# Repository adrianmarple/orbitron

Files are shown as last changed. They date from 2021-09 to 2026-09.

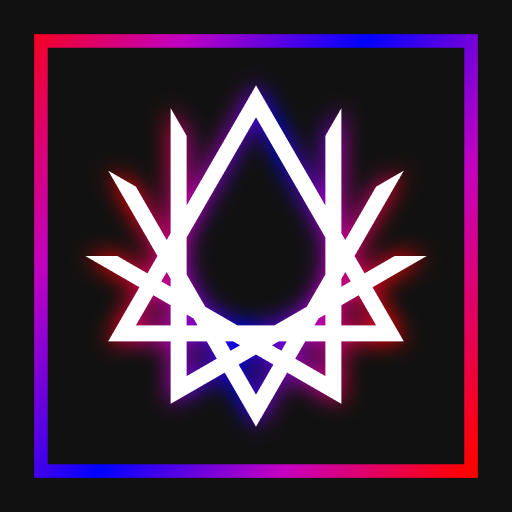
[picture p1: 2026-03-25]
controller/images/ravenstearborder.png

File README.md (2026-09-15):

# Basics

Lumatron is a LED sculpture system. You are free to play with this code, but as per the license you may not make money from it.

## TL;DR
```
       ┌──────────────┐  ┌──────────────┐  ┌──────────────┐
       │  Controller  │  │    Admin     │  │   Emulator   │
       │   (browser)  │  │   (browser)  │  │   (browser)  │
       └──────┬───────┘  └──────┬───────┘  └──────┬───────┘
              │ WSS :7777       │ HTTPS           │ WSS
              ▼                 ▼                 ▼
       ┌──────────────────────────────────────────────────┐
       │             Relay server (HTTPS + WSS)           │
       │           e.g. my.lumatron.art / localhost       │
       └──────┬─────────────────┬─────────────────────────┘
              │                 │                   ▲
              │ WSS             │ WSS (out)         │
              ▼                 ▼                   │
       ┌──────────────┐  ┌─────────────┐            │ stls
       │ Raspberry Pi │  │   Arduino   │◄─────────┐ │
       │ Node + Py    │◄─│  esp32.ino  │──────────┤ │
       └──────┬───────┘  └────┬────────┘   pixels │ │
              │ drives        │ drives       info │ │
              ▼               ▼                   │ │
       ╔═══════════════════════╗         ┌────────┴─┴────┐
       ║   Physical piece      ║◄────────┤   Creation    │
       ║   (LED sculpture)     ║ designs │ console (dev) │
       ╚═══════════════════════╝         └───────────────┘
```

- Orbs always connect *outbound* to the relay, so they work behind NATs without port forwarding.
- The relay routes controller / admin / emulator messages to the right orb over its open WebSocket, and serves the websites for the controller, admin, and emulator.
- The Creation console is a dev-time tool (port 8000): it designs the physical piece (3D-printable parts) and writes geometry (pixel info and stls) into the repo.
- Each physical piece is driven by exactly one orb (Pi *or* Arduino).
- In dev (`DEV_MODE: true`), a single machine plays all roles: relay, local Pi-style orb, and emulator standing in for a real piece.

## Connecting an existing piece to the internet

Here's how to connect a piece that does not already have an internet connection (if no piece is already connected to the same wifi you're on these instructions can also be viewed by visiting `https://my.lumatron.art`)
- Plug in the Lumatron box into the power source and the box into the piece (do not plug the piece directly into the usb-c wall plug)
- Wait for the box to boot up and the access point pattern (waves eminating from the bottom point) to show (takes a couple minutes for the raspberry pi based boxes)
- Join the wifi named Lumatron-*name*
- (If the captive portal doesn't automatically appear) visit 10.42.0.1 in your browser.
- Enter the wifi name (SSID) and password in the captive portal
- Visit or refresh `https://my.lumatron.art` once the first pixel turns off

## Controlling a piece

- Visit `https://my.lumatron.art`
- (optional) Turn the site into a progressive web app by following the instructions at the bottom of the page

# Using the Emulator

- Clone (optionally fork first) this repo (`git clone https://github.com/adrianmarple/orbitron`) on your local machine (Windows not supported)
- cd to the root of the repo (folder should be named `orbitron`)
- Install node if you haven't already
- Run `scripts/admin_install.sh` (in the `scripts` folder of the newly cloned repo)
- Start the emulator by running `sudo ./startscript.sh`
- Visit `http://localhost:1337` for the controller
- Visit `http://localhost:1337/test/view` for the emulator (which also contains a controller)

## The admin console

- Make sure you've run `./admin_install.sh`
- Ensure the local server (`sudo ./startscript.sh`) is running
- Visit url `http://localhost:1337/admin`
- Follow instructions for entering a master key
- More details in [the admin folder README](admin)

# Designing a new pattern

See [the idlepatterns folder README](idlepatterns)

# Making a new Game

See [the games folder README](games)

# Setting up your own server

- Fork this repo
- Create an ubuntu server, for instance the lumatron.art is currently hosted through [Digital Ocean](https://www.digitalocean.com/)
- Add a domain (or subdomain of an existing domain you control) to the server (this is required to serve over https)
- Wait and make sure the DNS records are in place (i.e. by checking [https://www.whatsmydns.net/](https://www.whatsmydns.net/))
- Open a console into root of your new server
- Clone your forked repo, i.e. `git clone https://github.com/YOUR_GITHUB_NAME/orbitron`
- Run `cd orbitron` then `scripts/server_install.sh` and enter your domain (and eventually email and other certbot prompts)
- Test by visiting `https://your_domain.com` (you should see "No pieces found on the same wifi")

## Connect a piece to your own server

- Arduino
  - Clear entire arduino flash `esptool.py --chip esp32c3 --port /dev/ttyUSB0 erase_flash`
  - Edit arduino/esp32/esp32.ino: find and replace "my.lumatron.art" with your server
  - Install adruino cli if you haven't already: `scripts/arduino_install.sh`
    - Note two github hooks are installed with this script. One runs `scripts/arduino_build.sh` on git push and uploads the compiled firmware to the server
    - The server url is currently hardcoded, so you should edit "arduino_build.sh" to use your own server, if you want to push to your own repo.
  - Upload to the arduino using `scripts/arduino_upload.sh`
- Raspberry pi
  - Request an unlocked SD along with a piece, email adrian@marplebot.com an request it be unlocked remotely, or follow the **Micro SD card setup** instructions below
  - Get local IP address (once the admin console is set up, you'll be able to get the ip address directly from there)
    - MacOS: `sudo nmap -sn $(ipconfig getifaddr en0)/24`
    - Linux: `sudo nmap -sn $(hostname -I | cut -d' ' -f1)/24`
  - `ssh pi@<IP address>` (password `lumatron`) into the piece
  - Change the password by running `passwd`
  - Edit `orbitron/config.js` to add the line `RELAY_HOST: "your-domain-or-ip",` (also remove `ORB_KEY` if it's there)
  - Run `pm2 restart all`
- Test by visiting `https://your_domain.com` again (you should now see the piece)

## The admin console

- Ensure your server is properly set up
- Visit url `https://your-domain.com/admin`
- Enter the masterkey (from `masterkey.txt` from your server's console) as prompted
- I recommend hitting the "Set ORB_KEY" button followed by the "Save config.js" button for all connected orbs (including the server itself - default named "demo")
  - Note: if this button is not visible hit the "config" button first
- Again see [the admin folder README](admin) for more details

## Continuous integration

You can set up pieces so that pushing to github automatically triggers pieces to restart and pull changes:
- Direct a github action to point to your server
- Add `CONTINUOUS_INTEGRATION: true,` to the config of a piece you want to restart on receiving updates

# REST API

Most things the controller can do can also be done over plain HTTP (useful for scripting: Home Assistant, Shortcuts, cron, or any other forms of automation). This includes preferences, saved presets, the timer schedule, and dimming, but omits game inputs. It is served by the server (i.e. `my.lumatron.art`) under `/api/v1`.

`GET /api/v1/orbs` lists the pieces available to you. Every other path is relative to `/api/v1/orbs/<piece>`, where `<piece>` is a piece's name or its alias (e.g. `https://my.lumatron.art/api/v1/orbs/kitchen/prefs`).

| Method | Path | Body | Description |
|---|---|---|---|
| `GET` | `/prefs` | — | All current settings (pattern, colors, brightness) |
| `PATCH` | `/prefs` | `{"<key>": value, ...}` | Change one or more settings, leaving the rest alone |
| `DELETE` | `/prefs` | — | Reset all settings back to defaults |
| `POST` | `/dim` | — | Step brightness, the same as the hardware button |
| `GET` | `/presets` | — | Saved preset names, which one is current, and cycle membership |
| `PUT` | `/presets/<name>` | — | Save the current settings as `<name>` |
| `POST` | `/presets/<name>/load` | — | Switch to `<name>` |
| `DELETE` | `/presets/<name>` | — | Delete `<name>` |
| `POST` | `/presets/<name>/copy` | `{"copyName": "..."}` | Copy `<name>` to a new preset |
| `POST` | `/presets/<name>/rename` | `{"newName": "..."}` | Rename `<name>` |
| `POST` | `/presets/<name>/reorder` | `{"targetName": "..."}` | Move `<name>` in front of `targetName` |
| `POST` | `/presets/cycle` | — | Advance to the next preset in the cycle |
| `GET` | `/schedule` | — | Timer settings, plus the daily and weekly schedules |
| `PUT` | `/schedule` | `{"useTimer": true, "schedule": [...]}` | Update timer settings |
| `GET` | `/state` | — | All of the above at once |

Preset names may contain spaces, so URL-encode them (`/presets/Evening%20Glow/load`).

A few things worth knowing:
- There's no authentication by default, which is the same as the controller — anyone who knows a piece's name can already control it. To lock it down, add `REST_API_KEY: "some-secret",` to your server's `config.js` and send `Authorization: Bearer some-secret` with every request.
- `GET /api/v1/orbs` only lists pieces on the same wifi as whoever is asking, so the whole fleet isn't enumerable.
- The API connects to a piece the same way a controller does, but without claiming one of the six player slots, so it won't interfere with games or with anyone using the controller. Changes made either way show up in the other immediately.

See [API.md](API.md) for the full endpoint reference.

# Contributions Welcome

Here's a list of things I would welcome receiving PRs for.

- New idle patterns — See [idlepatterns/README.md](idlepatterns/README.md) for details
- New games — See [games/README.md](games/README.md) for details
- Clarifications or other improvements to any READMEs
- UX improvements or other quality of life features for the controller
- General optimizations or improvements

# Arduino setup
Requires a Xiao esp32c3, esp32c6, or esp32s3
- Run `scripts/arduino_install.sh`
- Plug into your computer
- Run `scripts/arduino_upload.sh` to compile and upload to your arduino
- For the first time after installing, check for an access point and add a wifi connection

# Raspberry Pi setup

- Download [an unlocked SD card image](https://www.dropbox.com/scl/fi/ce7uv4ptdwy640emwvc8e/lumatron.zip) from dropbox
- Burn to SD card using `dd` or [Balena Etcher](https://etcher.balena.io/)
- Using `dd`
  - Update `/dev/disk4` or `/dev/sda` below with the correct drive as determined from `diskutil list` or `lsblk` on Linux
  - `diskutil unmountDisk /dev/disk4` or `sudo umount /dev/sda1 && sudo umount /dev/sda2` on Linux
  - go to Download directory or wherever the SD image download is
  - `sudo dd if=lumatron.img of=/dev/disk4 status=progress`
  - On MacOS use `gdd` instead
    - Install with `brew install coreutils`
    - `sudo gdd if=lumatron.img of=/dev/disk4 status=progress`
- Insert SD card into raspberry pi and power on
- Connect via `ssh pi@<<IP_ADDRESS>>` password `lumatron`
- Change to your own password

## (alternative) Fresh Setup

### Image an SD card

- Download Raspberry Pi Imager: https://www.raspberrypi.org/software/
- Select the latest 64-bit Raspberry PI OS
- Click the gear icon to change the settings of the install
- Set hostname to `orbitron`
- Enable SSH with password authentication
- enter pi as the username and enter a password
- Configure wireless LAN to connect to your local wifi
- Set timezone and select us Keyboard layout
- Save and click `WRITE` to burn the image
- Plug SD Card into PI

### Getting connected

- Connect PI to monitor/TV via HDMI cable
- Connect USB keyboard to PI as well
- Power on the PI
- Wait for some time, it may need to reboot 2 or more times
- You should see `orbitron login:` when it is ready
- Login with the username and password you set

### Install git

- `sudo apt install git`

### Clone Repo and run installer

- `git clone https://github.com/adrianmarple/orbitron`
- `~/orbitron/scripts/pi_install.sh`

# Additional useful things of note

## Ripping a new SD card version
- Update `/dev/disk4` below with the correct drive as determined from `diskutil list` or `lsblk`
- `sudo dd if=/dev/disk4 of=lumatron.img bs=8M count=820 status=progress`
- On MacOS use `gdd` instead
  - Install with `brew install coreutils`
  - `sudo gdd if=/dev/disk4 of=lumatron.img bs=8M count=820 status=progress`

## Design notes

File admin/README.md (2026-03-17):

# Basic setup

- Run `./admin_install.sh` (in the `scripts` folder)
- Local version:
  - Run the local server `sudo ./startscript.sh` in the repo root
  - Visit url `http://localhost:1337/admin`
- Server version (assuming you've setup your own server):
  - Visit url `https://your-domain-or-ip/admin`

# Admin console

Note, each Lumatron piece in code is called an "orb" (for legacy reasons related the former name, Super Orbitron).

## "Orb" list (right side)

The right side features a list of all orbs connected to the relay (or local relay if using `?local`). This list gets checked every 10 seconds.

## Functions (left side)

### Editing "orb" local files

There are 3 files that can be edited directly by clicking on the corresponding button and either typing ctrl-s or hitting the corresponding "Save [X]" button (which will restart the corresponding orb).
- config: this is the most important one. It lets you change the fundamentals of the orb. Check `config.js.template` in the repo root for examples.
  - When in this view there are "Generate ORB_ID" and "Set ORB_KEY" buttons visible.
    These edit the scratch `config.js` in the center, but you still need to save for them to take any effect.
- prefs: the `prefs.json` that controls the idle patterns, same as is manipulated by a controller.
- timing: the `timingprefs.json` that saves all other pref values, including dim state.

### Other commands

- Issue commands: a cheap ssh-like capability I added to be able to handle edge cases
  - Unlock Orb: resets the pi's password to "lumatron"
- All Backups: allows you to restore any orb from backup (saved by each orb at midnight), or force a manual save now with a custom name.
- Power Calibration: used to figure out the max power of an orb; used when in sight of the orb being calibrated
- Restart: self-explanatory
- Controller: opens the controller for this orb in a new tab (even if not connected to the same wifi)

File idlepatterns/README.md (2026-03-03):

# Idle Patterns

Idle patterns are the LED animations displayed when no game is active. Each pattern is a Python file that subclasses `Idle` (from `idlepatterns/__init__.py`), which itself subclasses `Game`.

## How It Works

`__init__.py` defines the `Idle` base class and the `set_idle()` function. When the active pattern changes (via controller prefs), `set_idle()` dynamically imports the new pattern module and calls `engine.start()` on it.

Each pattern overrides `render()` (or uses the base class rendering pipeline) to write values into `engine.raw_pixels` each frame. The base `Idle.render()` provides:
- **Frame pacing** — waits until the next frame is due
- **Fade** — applies `prefs.fade()` decay to `render_values`
- **Blending** — smooth interpolation between frames via `blend_pixels()`
- **Color** — applies color mode (fixed, rainbow, gradient, tricolor) via `apply_color()`
- **Brightness** — scales output by brightness pref (quadratic) and beat factor

## Adding a New Pattern

- Create `idlepatterns/mypattern.py`
- Subclass `Idle` and set `name = "mypattern"`
- Override `update()` for per-frame logic and/or `render()` for full custom rendering
- Add the pattern to `patternOptions()` in either the `options` list or the `includableOptions` list
  - If in `includableOptions` you'll need to add `INCLUDE: {mypattern: true},` to an orb's config for it to appear in that orb's controller
- If you want any additional parameters visible in the controller
  - Add them to the `default_prefs` dict in `prefs.py`
  - Access them via `prefs.get_pref('mypref')` in `mypattern.py`
  - Add new UI elements in `controller.html` to the `<!-- PATTERN MENU -->` section, imitating existing examples. Make sure to condition on that pattern being selected

## Existing Patterns

| Pattern | Description |
|---|---|
| `default` | Fluid fire that spreads via neighbor graph, squared brightness. Defined in `__init__.py`. |
| `fireflies` | Like default without branching and with directional propagation bias (`patternBias`). |
| `static` | Directional gradient — dot product of pixel coords with a direction vector. Optionally rotates over time. |
| `sin` | Traveling or radial sine wave along a configurable direction. `sinMin` sets brightness floor. |
| `linesine` | Sine wave along a 1D line/ring topology. Only valid when no pixel has more than 2 neighbors. |
| `pulses` | Expanding spherical ring pulses spawned from random points. Width controlled by `rippleWidth`. |
| `lightfield` | Each pixel oscillates independently at a random frequency and phase. |
| `lightning` | BFS spanning tree from a random sink; traces paths from random sources with exponential distance falloff. |
| `hourglass` | Fills pixels top-to-bottom over a configurable daily time window (`hourglassStart`/`hourglassEnd`). |
| `weather` | Sine wave modulated by live weather data (wind direction, temperature, UV, rain) via OpenWeatherMap. Requires `LAT`, `LON`, and `WEATHER_API_KEY` in `config.js`. |

## Key Prefs

Most patterns read from `prefs.py` via `get_pref()`. Common ones:

| Pref | Used by |
|---|---|
| `idleDensity` | default, fireflies, lightning, pulses, sin |
| `idleFrameRate` | all (speed, only related to frameRate for default and fireflies) |
| `idleBlend` | all (blend smoothing) |
| `idleColor` | all (color mode) |
| `brightness` | all |
| `patternBias` | fireflies |
| `staticDirection`, `staticRotation`, `staticRotationTime` | static |
| `sinDirection`, `sinMin`, `sinRadial` | sin, weather |
| `rippleWidth` | pulses |
| `hourglassStart`, `hourglassEnd` | hourglass |

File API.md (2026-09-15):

# Lumatron REST API

A JSON HTTP API for preferences, saved presets, and the timer schedule.
It is served by the **relay** under `/api/v1`.

Internally it connects to each orb as a virtual controller client, speaking the same WebSocket
message set `controller/controller.js` uses. Nothing is special-cased per device, so it works
identically for Raspberry Pi orbs and Arduino (ESP32) orbs.

```bash
curl -X PATCH https://my.lumatron.art/api/v1/orbs/myorb/prefs \
  -H 'Content-Type: application/json' \
  -d '{"brightness":40,"idlePattern":"fireflies"}'
```

## Authentication

None by default — the same exposure the WebSocket controller already has, where knowing an orb ID
is enough to control it.

To require a token, set `REST_API_KEY` in `config.js` on the relay; every request must then send
`Authorization: Bearer <that value>` or get `401`.

Orbs with `REQUIRES_LOGIN` cannot be driven through this API at all: they expect a 4-digit code
displayed on the orb itself, which a headless client can't read. Those return `403`.

## Orb IDs

The `:orb` path segment accepts either the orb ID or its alias (added to the relay's config.js).

---

## Endpoints

### Orbs

| Method | Path | Description |
|---|---|---|
| `GET` | `/api/v1/orbs` | Orbs on the caller's own network |

Scoped by source IP, so other orbs aren't exposed. Orbs configured with `NO_LOCAL_REGISTRATION` are omitted.

```json
[ { "id": "myorb", "alias": "kitchen", "isArduino": false, "connected": true } ]
```

### State

| Method | Path | Description |
|---|---|---|
| `GET` | `/api/v1/orbs/:orb/state` | The orb's lighting state in one call |

`prefs`, `prefNames`, `currentPrefName`, and `currentText`. `gameInfo` is omitted, since this API
doesn't cover games.

### Preferences

| Method | Path | Body | Description |
|---|---|---|---|
| `GET` | `/api/v1/orbs/:orb/prefs` | — | All current preferences |
| `PATCH` | `/api/v1/orbs/:orb/prefs` | `{"<key>": value, ...}` | Set one or more preferences |
| `DELETE` | `/api/v1/orbs/:orb/prefs` | — | Reset to defaults (`clearPrefs`) |

`PATCH` is a partial update — omitted keys are untouched. Unknown keys are rejected with `400`
rather than silently dropped, so a typo is visible:

```json
{ "error": "Unknown preference(s): brightnes" }
```

The authoritative key list is whatever `GET /prefs` returns for that orb, since it varies with
firmware version. The main ones:

| Key | Type | Default | Pi only | Description |
|---|---|---|---|---|
| `idlePattern` | enum | `"default"` | | Which animation runs: `default`, `static`, `fireflies`, `lightning`, `pulses`, `sin`, `lightfield`, `hourglass`, `linesine`, `weather`. `hourglass` and `weather` are Pi only. An orb's config can override the default with `IDLE`. |
| `idleFrameRate` | number | `15` | | Animation speed, for every pattern — an actual frame rate only for `default` and `fireflies`. Controller range 5–30. |
| `idleBlend` | number | `60` | | How much of the previous frame each frame blends in (motion smear). Unused by `weather`, `static`, `sin`, `lightfield`. |
| `idleDensity` | number | `70` | | How much is lit at once — head/source count for `default`, `fireflies`, `lightning`, `pulses`, `sin`. Minimum 10. |
| `staticRotation` | bool | `false` | | `static`: sweep the direction over time instead of holding `staticDirection`. |
| `staticRotationTime` | number | `8` | | `static`: seconds per full rotation, when `staticRotation` is on. |
| `staticDirection` | vector | `"1,1,0"` | | `static` (and `hourglass`): the axis the gradient runs along. |
| `patternBias` | vector | `"0,1,0"` | | `fireflies`: the direction the fireflies tend to travel. |
| `useBias` | bool | `true` | ✓ | The controller's "Use bias" toggle beside `patternBias`. Stored only — the render pipeline always applies the bias vector. |
| `rippleWidth` | number | `9` | | `pulses`: width of each expanding ring, 1–50. |
| `sinDirection` | vector | `"1,0,0"` | | `sin`: the direction the wave travels. Ignored when `sinRadial` is on. |
| `sinMin` | number | `25` | | `sin`: the trough value; the wave always peaks at 255. Negative values (down to -255) render as black but still shape everything above the trough. |
| `sinRadial` | bool | `false` | ✓ | `sin`: waves start at the center and move outward instead of travelling along `sinDirection`. |
| `sinRadialReverse` | bool | `false` | ✓ | `sin`: with `sinRadial` on, move inward instead. |
| `sinWaveCycles` | number | `4` | | `linesine`: how many wave cycles fit around the line/ring, 1–10. |
| `disableBeatMode` | bool | `false` | ✓ | `default`: opt out of beat-reactive brightness, on orbs wired for it (`BEAT_PIN`). |
| `hourglassStart` | `"HH:MM"` | `"00:00"` | ✓ | `hourglass`: when the daily fill begins. |
| `hourglassEnd` | `"HH:MM"` | `"23:59"` | ✓ | `hourglass`: when it finishes. |
| `idleColor` | enum | `"gradient"` | | Color mode: `rainbow`, `fixed`, `gradient`, `tricolor`. |
| `brightness` | number | `100` | | Master brightness, applied quadratically. |
| `color1` | color | `"#25ff59"` | | `fixed`: the one color everything is drawn in. `gradient`: the color the brighter pixels take. `tricolor`: the first band. |
| `color2` | color | `"#00607c"` | | `gradient`: the color the dimmer pixels take. `tricolor`: the middle band. Unused by `fixed`. |
| `color3` | color | `"#ff00aa"` | | `tricolor`: the last band. Unused by every other mode. |
| `gradientThreshold` | number | `66` | | `gradient`: where the two colors meet — lower is more `color1`, higher is more `color2`. `tricolor`: where `color3` gives way to `color2`. Minimum 1. |
| `gradientThreshold2` | number | `100` | | `tricolor`: where `color2` gives way to `color1`. Unused by every other mode. Minimum 1. |
| `rainbowDuration` | number | `10` | | `rainbow`: seconds for one full cycle through the rainbow. |
| `rainbowFade` | number | `0` | | `rainbow`: how much of the rainbow is on the orb at once. `0` is a single solid color cycling over time. |

A ✓ in "Pi only" means the Arduino (ESP32) firmware doesn't carry that pref at all, so it never appears in that orb's `GET /prefs` and `PATCH`ing it returns `400 Unknown preference(s)`.

Colors are `#rrggbb` strings; directions are `"x,y,z"` strings.

The color slots and blend thresholds used to be one set per mode. Those names are still
accepted on `PATCH` and mapped onto the merged keys above, so existing scripts keep
working — but they are never reported back by `GET /prefs`, and a preset re-saved after
being loaded is rewritten with the new names:

| sent | applied as |
|---|---|
| `fixedColor` | `color1` |
| `gradientStartColor`, `gradientEndColor` | `color1`, `color2` |
| `tricolor1`, `tricolor2`, `tricolor3` | `color1`, `color2`, `color3` |
| `tricolorThreshold1`, `tricolorThreshold2` | `gradientThreshold`, `gradientThreshold2` |

`tricolor` needs an explicit `INCLUDE` in an orb's config to appear in the controller's
mode dropdown, but the API can select it either way.

### Brightness / dimmer

| Method | Path | Description |
|---|---|---|
| `POST` | `/api/v1/orbs/:orb/dim` | Step through `MANUAL_FADE_STEPS` (default on/off) |

The same action as the orb's hardware button and the controller's power button.

### Presets

| Method | Path | Body | Description |
|---|---|---|---|
| `GET` | `/api/v1/orbs/:orb/presets` | — | `{names, current, includedInCycles}` |
| `PUT` | `/api/v1/orbs/:orb/presets/:name` | — | Save current prefs as `:name` |
| `DELETE` | `/api/v1/orbs/:orb/presets/:name` | — | Delete `:name` |
| `POST` | `/api/v1/orbs/:orb/presets/:name/load` | — | Load `:name` |
| `POST` | `/api/v1/orbs/:orb/presets/:name/copy` | `{"copyName": "..."}` | Copy to a new name |
| `POST` | `/api/v1/orbs/:orb/presets/:name/rename` | `{"newName": "..."}` | Rename |
| `POST` | `/api/v1/orbs/:orb/presets/:name/reorder` | `{"targetName": "..."}` | Move before `targetName` |
| `POST` | `/api/v1/orbs/:orb/presets/cycle` | — | Advance to the next preset in the cycle |

Preset names may contain spaces, so URL-encode them: `/presets/Evening%20Glow/load`.

`POST /presets/cycle` is the cycle action. A preset that happens to be *named* `cycle` is still
reachable through the three-segment forms, e.g. `POST /presets/cycle/load`.

Which presets participate in `cycle` is controlled by `includedInCycles`, set through `PATCH /prefs`:

```bash
curl -X PATCH .../prefs -d '{"includedInCycles":{"Evening Glow":true,"Bright":false}}'
```

### Schedule

| Method | Path | Body | Description |
|---|---|---|---|
| `GET` | `/api/v1/orbs/:orb/schedule` | — | Current timer settings |
| `PUT` | `/api/v1/orbs/:orb/schedule` | see below | Update timer settings |

Accepts any subset of `useTimer`, `weeklyTimer`, `dimmer`, `schedule`, `weeklySchedule`,
`includedInCycles`.

```json
{
  "useTimer": true,
  "schedule": [
    { "prefName": "Evening Glow", "time": "18:30", "fadeIn": 10, "fadeOut": 30 },
    { "prefName": "OFF",          "time": "23:00", "fadeIn": 10, "fadeOut": 30 }
  ]
}
```

- `prefName` — an existing preset, or `"OFF"` to turn the orb off
- `time` — `"HH:MM"`, 24-hour
- `fadeIn` / `fadeOut` — seconds
- `weekday` — required in `weeklySchedule` only; `0` = Monday through `6` = Sunday

Events are validated before being sent to the orb; a bad entry returns `400` describing the problem
and nothing is applied. Setting `weeklyTimer: true` with an empty `weeklySchedule` expands the daily
schedule across all seven days.

---

## Responses

Write endpoints return the affected resource, re-read from the orb after it has applied the change.

| Code | Meaning |
|---|---|
| `200` | Applied and confirmed by the orb |
| `202` | Sent, but the orb didn't confirm in time — the returned state may be stale |
| `400` | Bad body, unknown preference key, or invalid schedule entry |
| `401` | `REST_API_KEY` is set and the bearer token was missing or wrong |
| `403` | Orb requires an on-orb login code |
| `404` | Unknown orb, unknown preset, or no such route |
| `503` | Orb is known but not currently connected |

CORS is open (`Access-Control-Allow-Origin: *`) and `OPTIONS` preflight returns `204`.

---

## Notes

- Writes are idempotent. Setting a value that's already current is accepted and changes nothing.
- Changes appear live in any connected controller, and controller changes are visible here
  immediately.

## Examples

```bash
B=https://my.lumatron.art/api/v1/orbs/myorb

# Warm dim light
curl -X PATCH $B/prefs -H 'Content-Type: application/json' \
  -d '{"idleColor":"fixed","color1":"#ff8800","brightness":25}'

# Save it, then come back to it later
curl -X PUT  "$B/presets/Cozy"
curl -X POST "$B/presets/Cozy/load"

# On at sunset, off at bedtime
curl -X PUT $B/schedule -H 'Content-Type: application/json' -d '{
  "useTimer": true,
  "schedule": [
    {"prefName":"Cozy","time":"18:30","fadeIn":10,"fadeOut":30},
    {"prefName":"OFF", "time":"23:00","fadeIn":10,"fadeOut":30}
  ]
}'

# Toggle like the hardware button
curl -X POST $B/dim
```

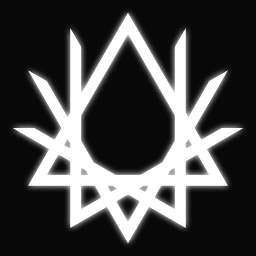
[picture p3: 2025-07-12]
controller/images/ravenstear_pretty.png

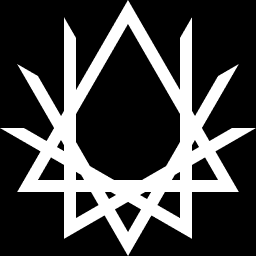
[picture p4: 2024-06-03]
controller/images/ravenstear.png

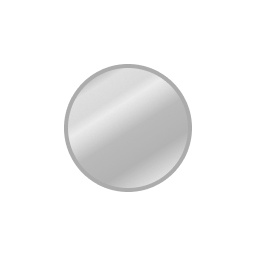
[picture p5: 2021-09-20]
controller/images/JoystickNub.png

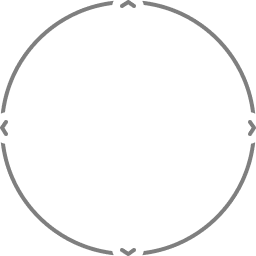
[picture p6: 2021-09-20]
controller/images/JoystickBG.png

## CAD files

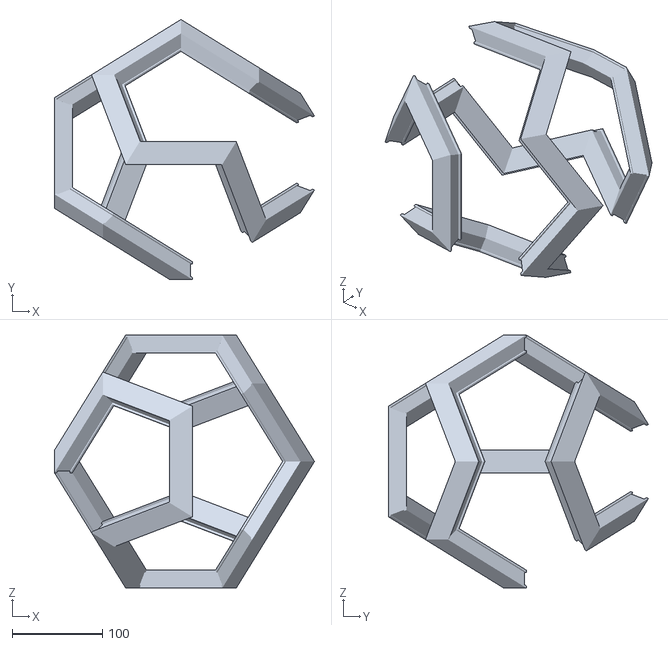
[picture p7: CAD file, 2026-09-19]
stls/archimedes/dodeccycle2_full.stl
288.3 x 288.3 x 280.6

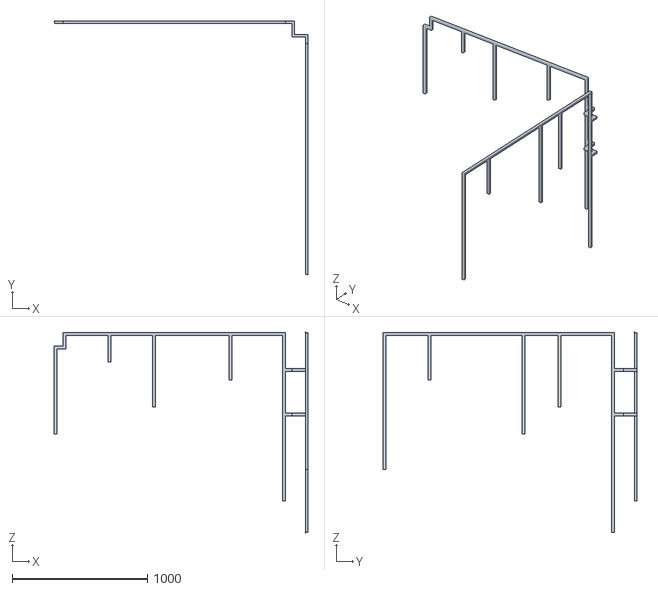
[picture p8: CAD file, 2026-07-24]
stls/family/panes_full.stl
1880.2 x 1880.2 x 1480.5

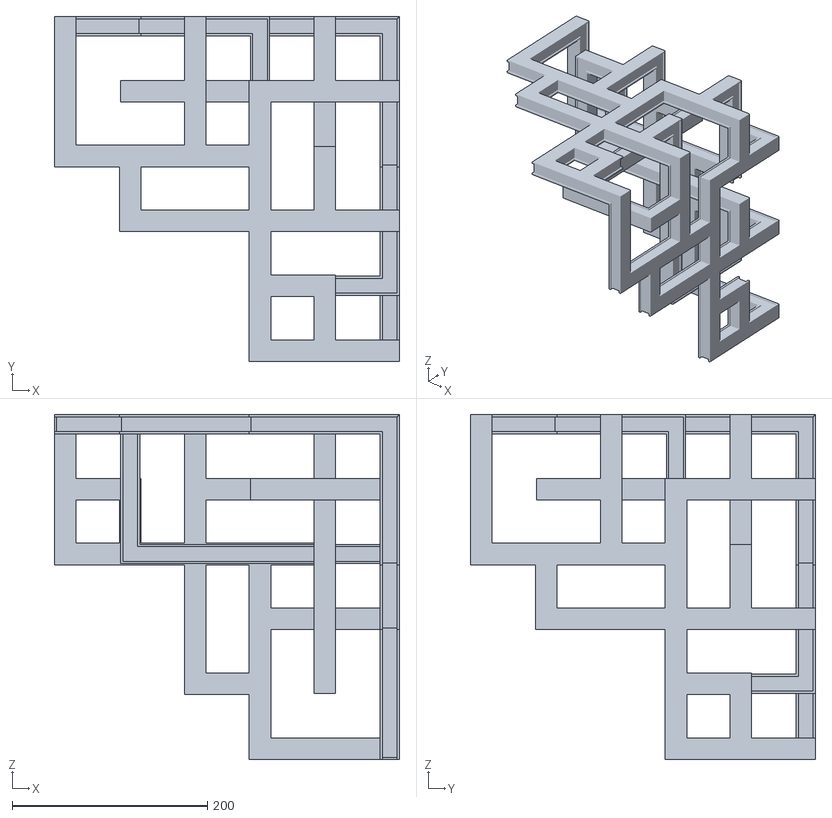
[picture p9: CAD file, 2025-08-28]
stls/math/borromeanoctant2_full.stl
353.1 x 353.1 x 353.1

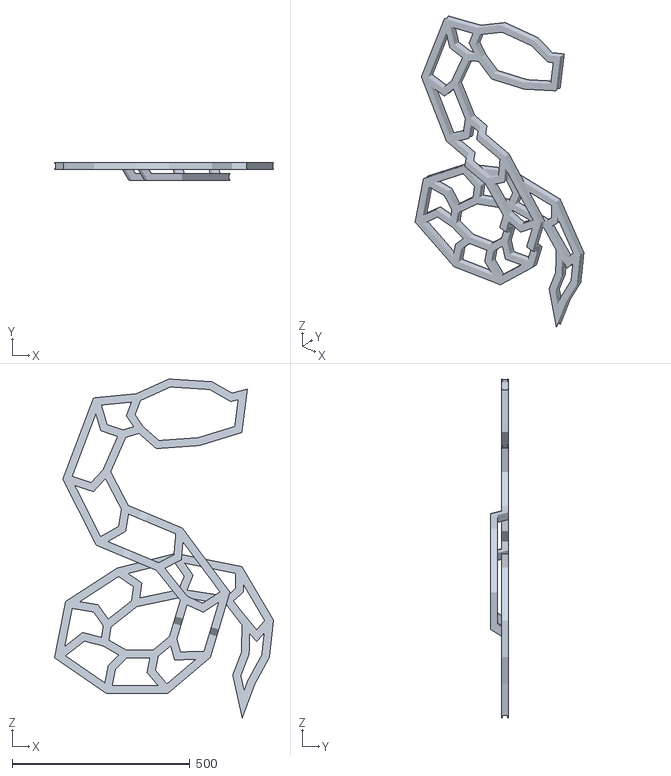
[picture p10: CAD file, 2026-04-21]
stls/organic/snake_full.stl
616.3 x 50.4 x 953.7

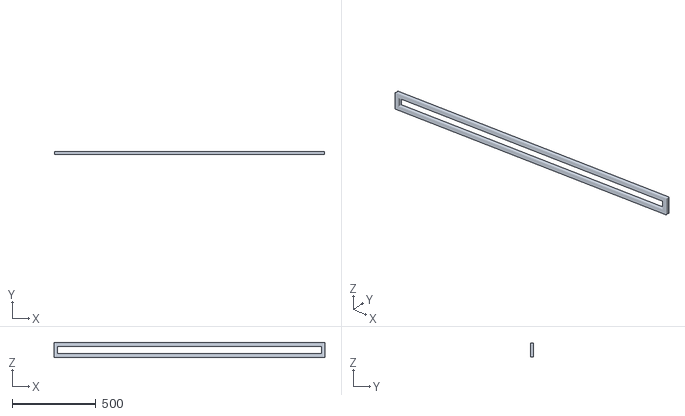
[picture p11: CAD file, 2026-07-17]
stls/random/barlight_full.stl
1615.8 x 19.8 x 88.6

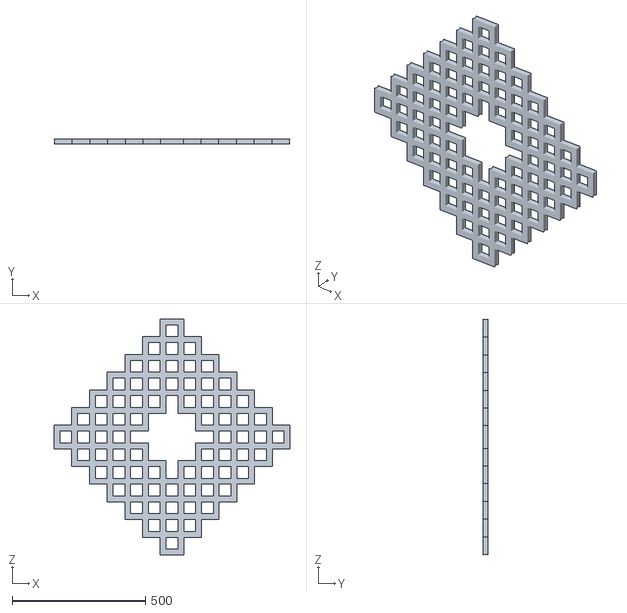
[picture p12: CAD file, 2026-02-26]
stls/squares/diamond_full.stl
885.4 x 19.9 x 885.4

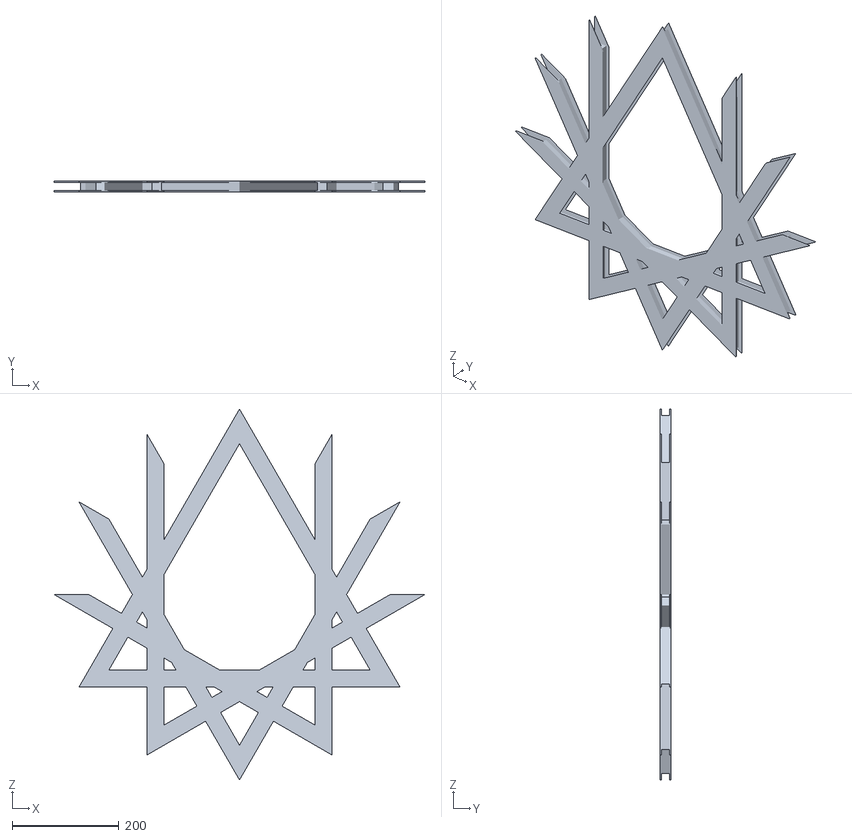
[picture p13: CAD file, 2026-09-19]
stls/sixfold/ravenstear_full.stl
694.0 x 19.8 x 694.0

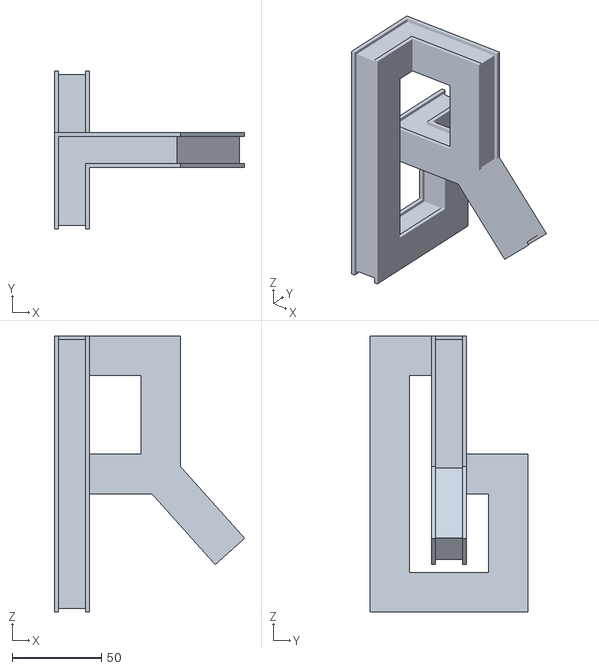
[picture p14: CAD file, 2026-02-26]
stls/test/mobius_full.stl
106.9 x 88.6 x 155.0

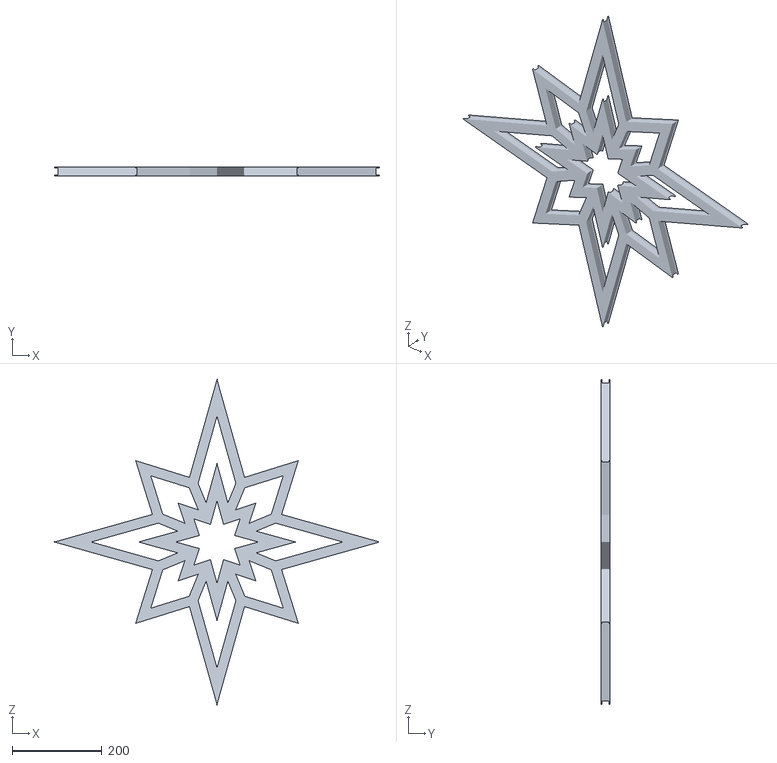
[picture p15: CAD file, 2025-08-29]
stls/sixfold/star4_full.stl
726.0 x 19.9 x 726.0

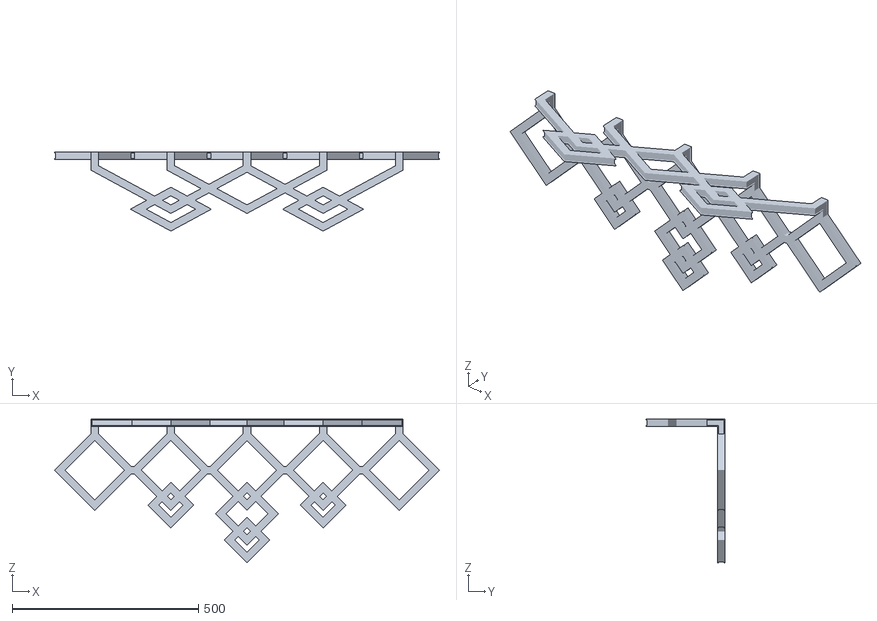
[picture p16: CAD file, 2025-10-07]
stls/squares/necklace_full.stl
1034.0 x 212.6 x 386.1

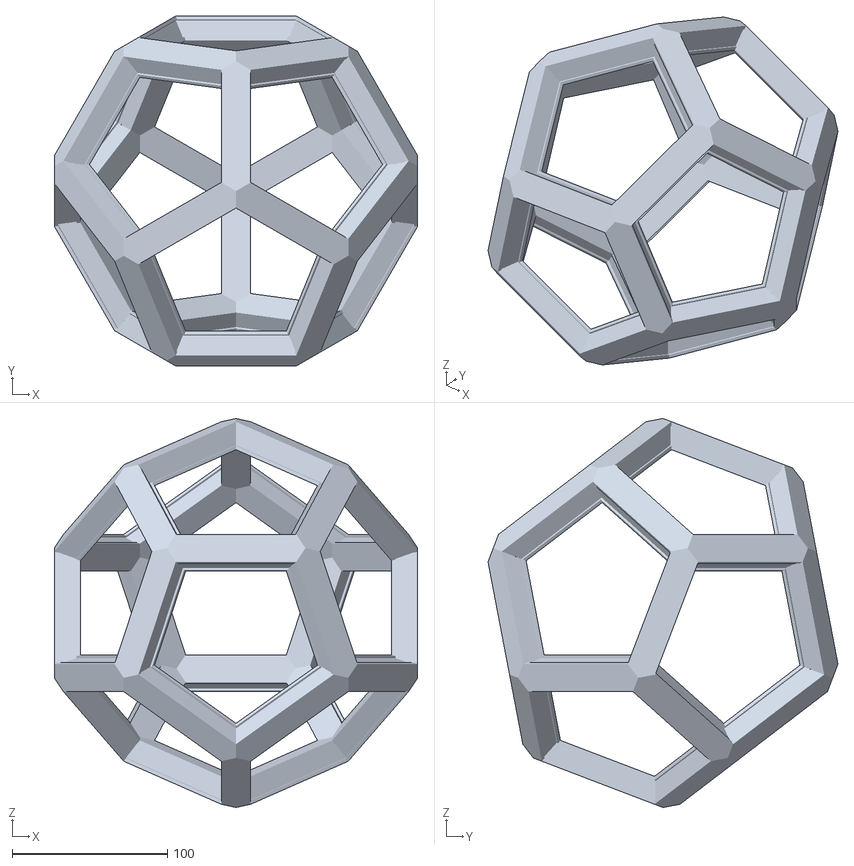
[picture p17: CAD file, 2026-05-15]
stls/archimedes/dodectrue_full.stl
234.1 x 225.5 x 250.6

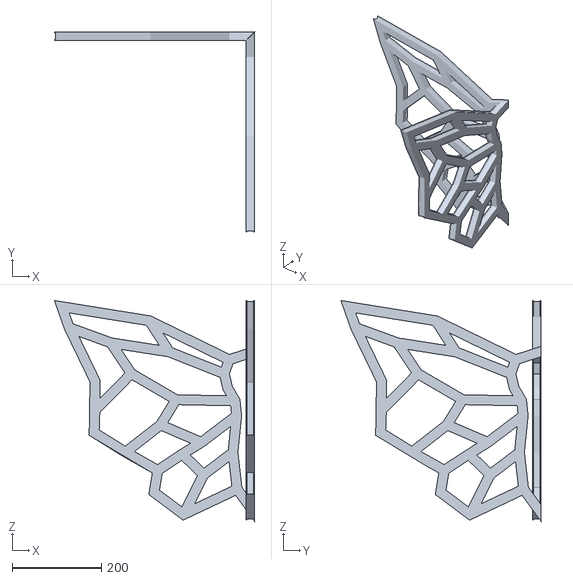
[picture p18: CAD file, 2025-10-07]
stls/organic/butterfly_full.stl
449.7 x 449.7 x 496.1

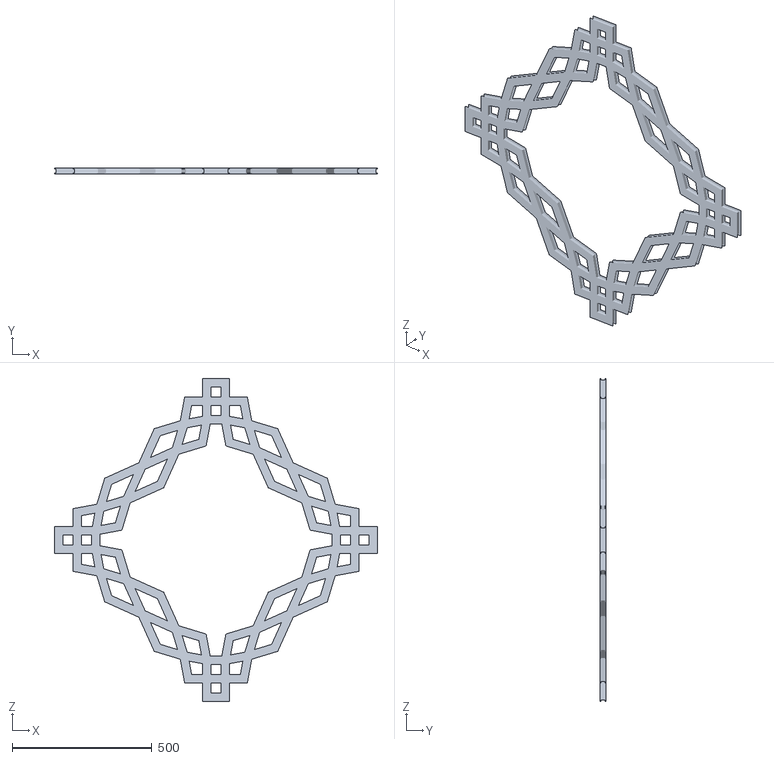
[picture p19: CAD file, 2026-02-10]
stls/random/mirror_full.stl
1155.6 x 19.8 x 1155.6

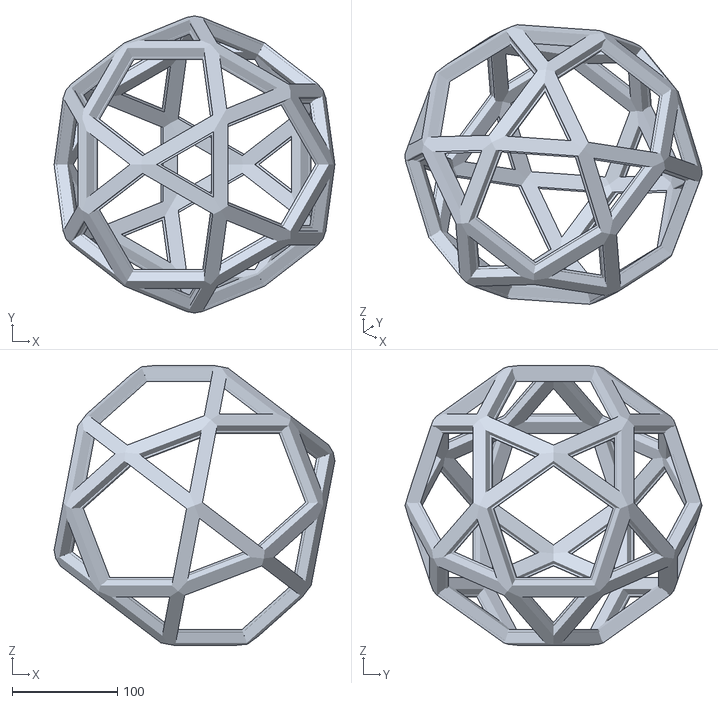
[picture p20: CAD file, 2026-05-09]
stls/archimedes/icosidodectrue_full.stl
266.7 x 282.1 x 266.1

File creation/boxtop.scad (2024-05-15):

$fn=32;
w = 72;
h = 108.2;
thickness1 = 2;
thickness2 = 3;

window_w = 51.8;
window_h = 22;
window_h_offset = 14.6;
magnet_r = 3.5;
magnet_offset = 1.5;

qr_base_w = 51.6;
qr_w = 48;
SCALE = 0.096 * 2.83464566929;

union() {
  difference() {
    cube([w, h, thickness1]);
      
    translate([(w - window_w)/2, h - window_h - window_h_offset, -1])
    cube([window_w, window_h, thickness1 + 2]);
      
    translate([0, 0, -1])
    union() {
      translate([magnet_r + magnet_offset, magnet_r + magnet_offset, 0])
      cylinder(h=thickness1, r=magnet_r);
        
      translate([w - magnet_r - magnet_offset, magnet_r + magnet_offset, 0])
      cylinder(h=thickness1, r=magnet_r);
        
      translate([w - magnet_r - magnet_offset, h - magnet_r - magnet_offset, 0])
      cylinder(h=thickness1, r=magnet_r);
        
      translate([magnet_r + magnet_offset, h - magnet_r - magnet_offset, 0])
      cylinder(h=thickness1, r=magnet_r);
    }
  }
  
  translate([(w - qr_base_w)/2, (w - qr_base_w)/2, thickness1])
  cube([qr_base_w, qr_base_w, thickness2]);


  translate([(w - qr_w)/2, (w - qr_w)/2, thickness1 + thickness2])
  scale([SCALE, SCALE, 1])
  linear_extrude(height = 0.2)
  import("/Users/adrianmarple/Dropbox/LumatronManufacturing/qr.svg");
}

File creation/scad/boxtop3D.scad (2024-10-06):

$fn=32;

thickness = 0.4;

MM_TO_DPI = 2.83464566929;
SCALE = 0.096 * MM_TO_DPI;
svg_file = "/Users/adrianmarple/Dropbox/LumatronManufacturing/qr.svg";

//scale([60/54, 60/54, 1])
union() {
  translate([-27,-27,0])
  scale([0.999, 0.999, 1])
  scale([MM_TO_DPI, MM_TO_DPI, 1])
  linear_extrude(height = thickness)
  import("qrframe.svg");

  translate([-24,-24,thickness])
  scale([SCALE, SCALE, 1])
  linear_extrude(height = 0.2)
  import(svg_file);
}

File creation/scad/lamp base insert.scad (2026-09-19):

$fn=128;

use <utils.scad>

r = 148/2;
outer_r = r;
h=23;
tripod_offset = 0;
button_r = 5.2;

front_oval = true;
oval_w = 25;
oval_h = 16;
oval_z = 13;

//r = 142.4/2;
//outer_r = 150/2;
//h = 23;
//tripod_offset = 25.16;
base_h = 2;
wall = 2;

screw_r = 5.2;
nut_r = 8.5;
//button_r = 6;

hole_r = 3;
hole_kerf = 0.1;
roundness = 2;

side_hole_z = 14.2;
side_hole_d = 14;//10.2;

arduino_w = 18;
arduino_l = 21.5;
arduino_pcb = 1.3;

usbc_offset = 2;
usbc_h = 3.6;
usbc_w = 9.3;

//bottom();
intersection() {
insert();
//translate([0,r,0])
//cube([40, 50, 50], center=true);
}

module bottom() {
  union() {
    linear_extrude(base_h+wall)
    offset(-roundness)
    offset(roundness)
    union() {
      difference() {
        circle(r=r);
        circle(r=r-wall);
      }
      translate([r - hole_r - wall, 0, 0])
      circle(r=hole_r+wall);
      translate([-(r - hole_r - wall), 0, 0])
      circle(r=hole_r+wall);
    }
    cylinder(h=wall, r=r);
    
  // Bottom connection holes
    hole_h = wall+base_h + 3;
    translate([r - hole_r - wall, 0, wall])
    cylinder(h=hole_h, r=hole_r-hole_kerf);
    translate([-(r - hole_r - wall), 0, wall])
    cylinder(h=hole_h, r=hole_r-hole_kerf);
  }
}

module insert() {
difference() {
  union() {
    linear_extrude(h)
    offset(-roundness)
    offset(roundness)
    union() {
      difference() {
        circle(r=r);
        circle(r=r-wall);
      }
      translate([r - hole_r - wall, 0, 0])
      circle(r=hole_r+wall);
      translate([-(r - hole_r - wall), 0, 0])
      circle(r=hole_r+wall);
    }
    cylinder(h=wall, r=r);
    //cylinder(h=wall + 4, r=nut_r+wall);
    
  }
  
  if (tripod_offset != 0) {
      for (i = [0,1,2]) {
          rotate([0,0,120*i])
          translate([0,25.16,0])
          cylinder(h=wall, r=screw_r);
      }
  }
  
  // Bottom connection holes
  translate([r - hole_r - wall, 0, wall])
  cylinder(h=h, r=hole_r);
  translate([-(r - hole_r - wall), 0, wall])
  cylinder(h=h, r=hole_r);
  
  // Nut
  cylinder(h=h, r=button_r);
  
  // arduino holder gap
  translate([0, r, h/2 + wall])
  cube([arduino_w + 2*wall, arduino_l + wall+10, h], center=true);
  
  // Oval for uncertainly placed side hole
  rotate([0,0,4])
  translate([0,-r+5,oval_z])
  rotate([90,0,0])
  hull() {
    translate([(oval_w-oval_h)/2,0,0])
    cylinder(h=10, r=oval_h/2);
    translate([-(oval_w-oval_h)/2,0,0])
    cylinder(h=10, r=oval_h/2);
  }
      
}

  // arduino holder
  difference() {
    union() {
      translate([-arduino_w/2 - wall, outer_r - usbc_offset - arduino_l - wall, 0])
      cube([arduino_w + 2*wall, arduino_l + 2*wall, side_hole_z-1.4]);
       
      translate([0, outer_r - usbc_offset-1, h/2])
      cube([arduino_w + 2*wall, 6, h], center=true);
      //cube([arduino_w + 2*wall, 6, side_hole_d+2], center=true);
    }
    
    difference() {
      cylinder(h=h+1, r=outer_r + 2);
      cylinder(h=h+1, r=outer_r);
    }
    
    //arduino itself
    translate([-arduino_w/2, outer_r - usbc_offset - arduino_l, side_hole_z - usbc_h/2 - arduino_pcb])
    cube([arduino_w, arduino_l, 5.2]);
    
    // back wire
    translate([-2, outer_r - usbc_offset - 1.5*arduino_l, side_hole_z - usbc_h/2 - arduino_pcb])
    cube([4, arduino_l, 10]);
    // pins troughs
    translate([-arduino_w/2, outer_r - usbc_offset - arduino_l, side_hole_z - usbc_h/2 - arduino_pcb - 2])
    cube([3, arduino_l, 7]);
    translate([arduino_w/2-3, outer_r - usbc_offset - arduino_l, side_hole_z - usbc_h/2 - arduino_pcb - 2])
    cube([3, arduino_l, 7]);
    
    //usbc hole
    translate([0, outer_r, side_hole_z])
    rotate([90,0,0])
    pillinder(usbc_w, usbc_h/2+0.1, 10);
  }
}

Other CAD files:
stls/sixfold/star3_full.stl
stls/random/line_full.stl
stls/archimedes/rhombtrue_full.stl
stls/archimedes/greatrhomb_full.stl
creation/scad/lumatron card.scad
creation/scad/jigs/solderjig_pi+pcb.scad
creation/scad/jigs/solderjig_wifiusb.scad
creation/scad/misc/powercore.scad
creation/scad/misc/powercore2.scad
creation/scad/misc/through nut.scad
creation/scad/misc/usbc hack mount.scad
creation/scad/mounts/angledstandoff.scad
creation/scad/mounts/microboxmount.scad
creation/scad/mounts/screwmount.scad
creation/scad/mounts/snapmount hook.scad
creation/scad/mounts/snapmount.scad
creation/scad/mounts/standoff.scad
creation/scad/mounts/swivelmount (intgrated).scad
creation/scad/mounts/swivelmount.scad
creation/scad/mounts/tripodmount.scad
creation/scad/neoorbitron/bottom.scad
creation/scad/neoorbitron/middle.scad
creation/scad/neoorbitron/strut corner.scad
creation/scad/neoorbitron/top.scad
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

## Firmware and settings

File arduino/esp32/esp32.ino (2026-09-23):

// WiFi-enabled Lumatron Arduino template for ESP32-C3/C6
// Requires libraries: WebSockets by Markus Sattler, ArduinoJson, LittleFS
// OTA firmware URL: https://<relayHost>/firmware/<orbID>.bin
// Pixel geometry fetched automatically from https://<relayHost>/pixels/<pixelsName>.bin
//
// On first boot with no /pixels.bin on flash:
//   set config.json: { "ORB_ID": "myorb", "PIXELS": "archimedes/octtrue" }
//   the device will download geometry on first WiFi connect and cache it to /pixels.bin

#include "ws2812_rmt.h"
#include <math.h>
#include <sys/time.h>
#include "mbedtls/sha256.h"
#include <WiFi.h>
#include <WiFiMulti.h>
#include <esp_wifi.h>
#include <WiFiClientSecure.h>
#include <DNSServer.h>
#include <WebServer.h>
#include "portal_html.h"
#include <WebSocketsClient.h>
#include <ArduinoJson.h>
#include <LittleFS.h>
#include <HTTPClient.h>
#include <HTTPUpdate.h>
#include <esp_sntp.h>

// Forward declaration so Arduino's auto-generated function prototypes (which
// it inserts right after this include block) can use Prefs& as a parameter
// type. The full struct is defined later in patterns.h.
struct Prefs;

#ifdef CONFIG_IDF_TARGET_ESP32C6
  #define PIN 18               // GPIO 18 = D10 on XIAO ESP32-C6
  #define DEFAULT_BUTTON_PIN 20 // GPIO 20 = D9  on XIAO ESP32-C6
  #define CHIP_TYPE "esp32c6"
#elif defined(CONFIG_IDF_TARGET_ESP32S3)
  #define PIN 9                // GPIO 9  = D10 on XIAO ESP32-S3
  #define DEFAULT_BUTTON_PIN 8  // GPIO 8  = D9  on XIAO ESP32-S3
  #define CHIP_TYPE "esp32s3"
#else
  #define PIN 10               // GPIO 10 = D10 on XIAO ESP32-C3
  #define DEFAULT_BUTTON_PIN 9  // GPIO 9  = D9  on XIAO ESP32-C3
  #define CHIP_TYPE "esp32c3"
#endif
#ifndef FIRMWARE_VERSION_NUM
#define FIRMWARE_VERSION_NUM 0
#endif
#define FIRMWARE_VERSION (String(FIRMWARE_VERSION_NUM))
#define PING_TIMEOUT_MS 30000
#define MAX_NEIGHBORS 6  // compile-time max; actual neighbor count per pixel determined by pixels.bin

// On S3 (which has OPI PSRAM), allocate geometry in PSRAM so internal DMA-capable
// RAM stays free for I2SClocklessLedDriver's I2S DMA buffers.
// ps_malloc/ps_calloc prefer PSRAM when available (PSRAM=opi in FQBN) and fall
// back to regular heap automatically. On C3/C6 (no PSRAM), use plain malloc/calloc.
#ifdef CONFIG_IDF_TARGET_ESP32S3
  #define GEO_MALLOC(sz)    ps_malloc(sz)
  #define GEO_CALLOC(n, sz) ps_calloc((n), (sz))
#else
  #define GEO_MALLOC(sz)    malloc(sz)
  #define GEO_CALLOC(n, sz) calloc((n), (sz))
#endif

// --- Geometry (loaded at runtime from /pixels.bin) ---
int SIZE = 0;
int RAW_SIZE = 0;
uint16_t (*dupes_to_uniques)[2] = nullptr;
uint16_t (*neighbors)[MAX_NEIGHBORS] = nullptr;
uint16_t *raw_to_unique = nullptr;
float (*coords)[3] = nullptr;
float bbox_min[3] = {0, 0, 0};
float bbox_max[3] = {0, 0, 0};

// --- Pattern state (heap-allocated in loadGeometry) ---
// Scratch: one shared block for pattern-specific arrays; carved per pattern by setupPatternScratch().
// SCRATCH_SIZE = RAW_SIZE*sizeof(float) + SIZE*sizeof(int16_t)*3
// (largest user is LIGHTNING: one float[RAW_SIZE] + three int16_t[SIZE])
uint8_t *scratch = nullptr;
size_t scratch_size = 0;
float *fluid_values = nullptr;       // DEFAULT, FIREFLIES: points into scratch
float *lightning_fluid = nullptr;    // LIGHTNING: points into scratch
int16_t *lightning_to_sink = nullptr;   // LIGHTNING: points into scratch
int16_t *lightning_distance = nullptr;  // LIGHTNING: points into scratch
int16_t *lightning_bfs_queue = nullptr; // LIGHTNING: points into scratch
float *pattern_target = nullptr;     // PULSES, LIGHTFIELD: points into scratch
float *linesine_positions = nullptr; // LINESINE: points into scratch
float *render_values = nullptr;      // permanent; used for inter-frame temporal smoothing

// --- Strip ---
// Renderers write into `pixels` (float RGB, AOS) without clipping, so additive
// blending has free headroom. stripShow() clips to 0..255 and packs into
// `leds` (GRB byte order, the WS2812 wire format) just before DMA. `leds`
// stays in internal SRAM because DMA needs it; `pixels` uses GEO_CALLOC, so
// on S3 it lands in PSRAM (frees ~18KB of internal SRAM at 1500 LEDs; the
// per-frame PSRAM access overhead is ~500-800us, well under the frame budget).
uint8_t *leds = nullptr;          // 3 bytes/LED in GRB order (matches WS2812 wire)
float (*pixels)[3] = nullptr;     // RGB float, [RAW_SIZE][3]

void stripShow() {
  if (!leds || !pixels) return;
  for (int i = 0; i < RAW_SIZE; i++) {
    float fr = pixels[i][0], fg = pixels[i][1], fb = pixels[i][2];
    if (fr < 0) fr = 0; else if (fr > 255) fr = 255;
    if (fg < 0) fg = 0; else if (fg > 255) fg = 255;
    if (fb < 0) fb = 0; else if (fb > 255) fb = 255;
    uint8_t* p = leds + i*3;
    p[0] = (uint8_t)fg;
    p[1] = (uint8_t)fr;
    p[2] = (uint8_t)fb;
  }
  ws2812_show(leds, RAW_SIZE * 3);
}

#include "patterns.h"

Prefs defaultPrefs = {
  PATTERN_DEFAULT,
  COLOR_GRADIENT, 0x25ff59, 0x00607c, 0xff00aa,
  66, 100, 10.0f, 0.0f,
  70.0f, 60.0f, 25.0f, 100,
  0.707f, 0.707f, 0.0f, 0, 8.0f,
  1.0f, 0.0f, 0.0f, 25, 9,
  0.0f, 1.0f, 0.0f, 4.0f
};

// --- Config ---
String orbID;
String relayHost;
String pixelsName;
String orbKey;  // sha256(orbID + masterKey); empty = no auth required
String timezone;    // raw TIMEZONE from config: either an IANA name or a POSIX TZ string
String resolvedTz;  // the POSIX TZ string actually handed to configTzTime
bool continuousIntegration = false;
bool dontReconnect = false;
WiFiMulti wifiMulti;  // multi-network connect; credentials live in /wifi.json
float maxAvgPixelBrightness = 0;  // 0 = disabled; 0-255 average per channel
bool fullBrightnessOnPowerOn = true;
bool skipAcOnPower = false;
// Boot-stability marker: /unstableboot is written each boot and only deleted
// after STABLE_UPTIME_MS of uninterrupted runtime, so its presence at boot means
// the previous run reset before stabilizing (the overcurrent-sag signature).
const unsigned long STABLE_UPTIME_MS = 10000;
bool bootStableMarked = false;

// --- Automated power calibration ---
// Binary searches MAX_AVG_PIXEL_BRIGHTNESS for the highest value the supply can
// actually sustain, using the same /unstableboot marker as the ratchet above as
// the pass/fail signal. State lives in /powercalibration.json so a probe that
// browns the chip out is resolved on the next boot. Only failures cost a reboot;
// a probe that survives its dwell advances the search in-process.
const int POWER_CALIBRATION_MARGIN = 5;          // backed off from the result before saving
const unsigned long POWER_CALIBRATION_DWELL_MS = 4000;  // how long a probe must hold to pass
const int POWER_CALIBRATION_MAX_PROBES = 12;     // termination guard; 8 suffices for 1..255
bool powerCalibrationActive = false;
bool powerCalibrationDirty = false;   // set on any state change; networkTask re-sends the info dump
String powerCalibrationResult = "";   // outcome, reported until the next reboot
int powerCalLo = 1;      // highest value known to hold
int powerCalHi = 255;    // highest value not yet proven to fail
int powerCalCand = 0;    // the probe in flight
int powerCalProbes = 0;
unsigned long powerCalProbeStart = 0;

// --- Manual fade pin ---
int buttonPin = 0;  // 0 = disabled (GPIO 0 isn't used as a button on any supported board)
String shortPressAction = "DIM";
String longPressAction = "CYCLE";
String extraLongPressAction = "ACCESS_POINT";
bool fadePinLastState = false;  // true = pressed
unsigned long fadePinPressStart = 0;
bool fadePinLongFired = false;
bool fadePinExtraLongFired = false;
const unsigned long LONG_PRESS_TIME = 700;
const unsigned long EXTRA_LONG_PRESS_TIME = 4000;
bool virtualButtonState = false;  // true = pressed; set by buttonStart/buttonEnd messages

// --- WebSocket ---
WebSocketsClient wsClient;
unsigned long lastPingReceived = 0;

// --- Connected controller client IDs ---
#define MAX_CLIENTS 8
String connectedClients[MAX_CLIENTS];
int clientCount = 0;
String currentPrefName = "";
uint32_t prefsHash = 0;  // fnv1a of last-written prefs.json; skips no-op rewrites

// Updates the in-memory name and writes to flash only if the value changed,
// avoiding a flash write per prefs tweak. writeFile holds render_mutex around
// the actual write, so the flash erase can't underrun the WS2812 DMA.
void setCurrentPrefName(const String& name) {
  if (currentPrefName == name) return;
  currentPrefName = name;
  writeFile("/currentprefname.txt", name);
}

// --- Geometry loaded flag ---
bool geometryLoaded = false;  // true once real geometry (SIZE > 1) is in memory

// --- Timing state ---
bool useTimer = false;
float dimmer = 1.0f;
String lastTriggeredEventKey = "";
unsigned long nextEventMs = 0;
JsonDocument timingPrefsDoc;  // in-memory cache of /timingprefs.json
uint32_t timingPrefsHash = 0; // fnv1a of last-written timingprefs; skips no-op rewrites

// --- State drift detection ---
// Cached hash of the most recent state JSON (excluding transient timestamp).
// Broadcast periodically as STATE_HASH:<hex> so controllers can detect drift
// from missed state messages and request a resync.
uint32_t currentStateHash = 0;
unsigned long nextStateHashMs = 0;
const unsigned long STATE_HASH_INTERVAL_MS = 3000;

inline uint32_t fnv1a(const char* s, size_t len) {
  uint32_t h = 2166136261u;
  for (size_t i = 0; i < len; i++) { h ^= (uint8_t)s[i]; h *= 16777619u; }
  return h;
}

// Fade state, recomputed by checkSchedule(). Published atomically under
// render_mutex so computeFade() (core 1) never reads a half-updated set.
bool fadeStateValid = false;
// Monotonic anchor for the current event's start. checkSchedule() converts the
// current event's wall-clock time into a millis() timestamp once per re-anchor
// (using a single simultaneous read of both clocks); computeFade() then drives
// the whole fade off millis() alone. nextEventMs is the matching far-end anchor.
// This keeps both ends of the fade on one monotonic clock, so a momentary
// wall-vs-millis disagreement at a boundary can only clamp the fade to 0 (dark),
// never wrap to a full day and pop to full brightness.
unsigned long curEventStartMs = 0;
bool curIsOff = true;
bool prevIsOff = true;
bool nextIsOff = true;
bool startSamePreset = false; // prev event's preset == active's: skip the fade-in
bool endSamePreset = false;   // next event's preset == active's: skip the fade-out
float prevFadeIn = 10.0f;     // minutes
float nextFadeOut = 30.0f;    // minutes

// Set by the SNTP sync callback (onTimeSync) whenever NTP steps the wall clock.
// networkTask re-anchors on the next loop so millis() deadlines computed from a
// stale/wrong wall clock get corrected. Also re-anchor periodically as a backstop.
volatile bool timeSyncPending = false;
unsigned long nextReanchorMs = 0;
const unsigned long REANCHOR_INTERVAL_MS = 60000;

// --- Backup state ---
unsigned long nextBackupMs = ULONG_MAX;

// --- Render mutex ---
// Taken by the network task when handling a WebSocket event (modifying shared state)
// and by every flash write (writeFile/removeFile), so a flash erase can never
// stall the CPU mid-frame and underrun the WS2812 DMA.
// Taken by loop() for the duration of each render frame.
// Recursive so nested holders (savePrefsAndApply -> savePrefs -> writeFile) don't deadlock.
// On S3: tasks run on separate cores so this prevents true concurrent access.
// On C3/C6: tasks share one core; mutex is still correct, just has no parallelism benefit.
SemaphoreHandle_t render_mutex = nullptr;
volatile bool apActive = false;
// Set by the button (polled in loop() so it responds before networkTask is up)
// and consumed by networkTask to launch the captive portal, which has to run
// on networkTask so loop() can keep rendering the AP rings.
volatile bool apTriggerRequested = false;


// ===================== PREFS =====================

// Format helpers shared by prefsToJson / prefsFromJson / sendState
const char* patternName(int p) {
  switch (p) {
    case PATTERN_STATIC:     return "static";
    case PATTERN_SIN:        return "sin";
    case PATTERN_PULSES:     return "pulses";
    case PATTERN_FIREFLIES:  return "fireflies";
    case PATTERN_LIGHTFIELD: return "lightfield";
    case PATTERN_LIGHTNING:  return "lightning";
    case PATTERN_LINESINE:   return "linesine";
    default:                 return "default";
  }
}
int patternFromName(const char* name) {
  if (!name) return PATTERN_DEFAULT;
  if (strcmp(name, "static") == 0)     return PATTERN_STATIC;
  if (strcmp(name, "sin") == 0)        return PATTERN_SIN;
  if (strcmp(name, "pulses") == 0)     return PATTERN_PULSES;
  if (strcmp(name, "fireflies") == 0)  return PATTERN_FIREFLIES;
  if (strcmp(name, "lightfield") == 0) return PATTERN_LIGHTFIELD;
  if (strcmp(name, "lightning") == 0)  return PATTERN_LIGHTNING;
  if (strcmp(name, "linesine") == 0)   return PATTERN_LINESINE;
  return PATTERN_DEFAULT;
}
const char* colorName(int c) {
  switch (c) {
    case COLOR_FIXED:    return "fixed";
    case COLOR_RAINBOW:  return "rainbow";
    case COLOR_TRICOLOR: return "tricolor";
    default:             return "gradient";
  }
}
int colorFromName(const char* name) {
  if (!name) return COLOR_GRADIENT;
  if (strcmp(name, "fixed") == 0)    return COLOR_FIXED;
  if (strcmp(name, "rainbow") == 0)  return COLOR_RAINBOW;
  if (strcmp(name, "tricolor") == 0) return COLOR_TRICOLOR;
  return COLOR_GRADIENT;
}
String colorToHex(long color) {
  char buf[8]; snprintf(buf, sizeof(buf), "#%06lx", color & 0xffffff); return String(buf);
}
long hexToColor(const char* hex) {
  if (!hex || hex[0] != '#') return 0; return strtol(hex + 1, nullptr, 16);
}
String dirToString(float x, float y, float z) {
  char buf[64]; snprintf(buf, sizeof(buf), "%g,%g,%g", x, y, z); return String(buf);
}
void parseDir(const char* s, float& x, float& y, float& z) {
  x = y = z = 0.0f; if (!s) return; sscanf(s, "%f,%f,%f", &x, &y, &z);
}

// Percent-encode a string for use as a URL path segment. The orb ID goes straight into
// the relay WebSocket path, and a character outside the unreserved set -- a space above
// all -- makes the HTTP request line malformed, so the relay never sees the real ID.
String urlEncodePath(const String& s) {
  static const char* HEX_DIGITS = "0123456789ABCDEF";
  String out;
  out.reserve(s.length() + 8);
  for (unsigned int i = 0; i < s.length(); i++) {
    char c = s[i];
    if (isalnum((unsigned char)c) || c == '-' || c == '.' || c == '_' || c == '~') {
      out += c;
    } else {
      out += '%';
      out += HEX_DIGITS[(c >> 4) & 0xf];
      out += HEX_DIGITS[c & 0xf];
    }
  }
  return out;
}

// Serialize prefs in controller-compatible (Python) format
void buildPrefsJson(JsonObject doc, Prefs& p) {
  doc["idleColor"]          = colorName(p.idleColor);
  doc["idlePattern"]        = patternName(p.idlePattern);
  doc["color1"]             = colorToHex(p.color1);
  doc["color2"]             = colorToHex(p.color2);
  doc["color3"]             = colorToHex(p.color3);
  doc["gradientThreshold"]  = p.gradientThreshold;
  doc["gradientThreshold2"] = p.gradientThreshold2;
  doc["rainbowDuration"]    = p.rainbowDuration;
  doc["rainbowFade"]        = p.rainbowFade;
  doc["brightness"]         = p.brightness;
  doc["dimmer"]             = dimmer;
  doc["idleBlend"]          = p.idleBlend;
  doc["idleDensity"]        = p.idleDensity;
  doc["idleFrameRate"]      = p.idleFrameRate;
  doc["staticDirection"]    = dirToString(p.staticDirX, p.staticDirY, p.staticDirZ);
  doc["sinDirection"]       = dirToString(p.sinDirX, p.sinDirY, p.sinDirZ);
  doc["patternBias"]        = dirToString(p.patternBiasX, p.patternBiasY, p.patternBiasZ);
  doc["staticRotation"]     = (bool)p.staticRotation;
  doc["staticRotationTime"] = p.staticRotationTime;
  doc["rippleWidth"]        = p.rippleWidth;
  doc["sinMin"]             = p.sinMin;
  doc["sinWaveCycles"]      = p.sinWaveCycles;
}

String prefsToJson(Prefs& p) {
  JsonDocument doc;
  buildPrefsJson(doc.to<JsonObject>(), p);
  String out;
  serializeJsonPretty(doc, out);
  return out;
}

Prefs prefsFromJson(JsonVariantConst doc, Prefs& base) {
  Prefs p = base;
  // Strings must be strings (they come from our own serialization)
  if (doc["idlePattern"].is<const char*>())
    p.idlePattern = patternFromName(doc["idlePattern"].as<const char*>());
  if (doc["idleColor"].is<const char*>())
    p.idleColor = colorFromName(doc["idleColor"].as<const char*>());
  // Presets written by firmware predating the shared palette name the gradient
  // pair separately. Read those first so the canonical keys win when both exist;
  // nothing writes them back, so a preset normalizes on its next save.
  if (doc["gradientStartColor"].is<const char*>())
    p.color1 = hexToColor(doc["gradientStartColor"].as<const char*>());
  if (doc["gradientEndColor"].is<const char*>())
    p.color2 = hexToColor(doc["gradientEndColor"].as<const char*>());
  if (doc["color1"].is<const char*>())
    p.color1 = hexToColor(doc["color1"].as<const char*>());
  if (doc["color2"].is<const char*>())
    p.color2 = hexToColor(doc["color2"].as<const char*>());
  if (doc["color3"].is<const char*>())
    p.color3 = hexToColor(doc["color3"].as<const char*>());
  if (doc["staticDirection"].is<const char*>())
    parseDir(doc["staticDirection"].as<const char*>(), p.staticDirX, p.staticDirY, p.staticDirZ);
  if (doc["sinDirection"].is<const char*>())
    parseDir(doc["sinDirection"].as<const char*>(), p.sinDirX, p.sinDirY, p.sinDirZ);
  if (doc["patternBias"].is<const char*>())
    parseDir(doc["patternBias"].as<const char*>(), p.patternBiasX, p.patternBiasY, p.patternBiasZ);
  // Numerics: use as<T>() so string "42" (from HTML range inputs) coerces correctly
  if (!doc["gradientThreshold"].isNull())  p.gradientThreshold  = doc["gradientThreshold"].as<int>();
  if (!doc["gradientThreshold2"].isNull()) p.gradientThreshold2 = doc["gradientThreshold2"].as<int>();
  if (!doc["rainbowDuration"].isNull())    p.rainbowDuration    = doc["rainbowDuration"].as<float>();
  if (!doc["rainbowFade"].isNull())        p.rainbowFade        = doc["rainbowFade"].as<float>();
  if (!doc["brightness"].isNull())         p.brightness         = doc["brightness"].as<int>();
  if (!doc["idleBlend"].isNull())          p.idleBlend          = doc["idleBlend"].as<float>();
  if (!doc["idleDensity"].isNull())        p.idleDensity        = doc["idleDensity"].as<float>();
  if (!doc["idleFrameRate"].isNull())      p.idleFrameRate      = doc["idleFrameRate"].as<float>();
  if (!doc["staticRotationTime"].isNull()) p.staticRotationTime = doc["staticRotationTime"].as<float>();
  if (!doc["rippleWidth"].isNull())        p.rippleWidth        = doc["rippleWidth"].as<int>();
  if (!doc["sinMin"].isNull())             p.sinMin             = doc["sinMin"].as<int>();
  if (!doc["staticRotation"].isNull())     p.staticRotation     = doc["staticRotation"].as<bool>() ? 1 : 0;
  if (!doc["sinWaveCycles"].isNull())      p.sinWaveCycles      = doc["sinWaveCycles"].as<float>();
  return p;
}

// ===================== FILE I/O =====================

// Saved presets use individual files matching the Pi format: /savedprefs/<name>.prefs.json
String savedPrefPath(const String& name) {
  return "/savedprefs/" + name + ".prefs.json";
}
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
void loop() {
  if (!leds || !pixels) {  // allocation error fallback
    delay(10);
    return;
  }

  xSemaphoreTakeRecursive(render_mutex, portMAX_DELAY);
  if (!leds || !pixels) {
    xSemaphoreGiveRecursive(render_mutex);
    delay(10);
    return;
  }

  unsigned long loop_start = millis();

  renderFrame();

  if (apActive) renderAPRings();

  stripShow();

  // Once we've rendered uninterrupted for STABLE_UPTIME_MS, clear the boot marker
  // so this boot no longer counts as unstable. removeFile nests harmlessly on the
  // render_mutex we already hold.
  if (powerCalibrationActive) {
    if (powerCalProbeStart == 0) {
      // Time the dwell from the first frame actually pushed to the strip, not from
      // when setup() picked the candidate -- nothing is lit until here, so starting
      // earlier would let a probe pass on time spent booting.
      powerCalProbeStart = millis();
    } else if (millis() - powerCalProbeStart > POWER_CALIBRATION_DWELL_MS) {
      // Held for the full dwell, so this candidate is good: disarm the marker
      // (nothing to resolve on the next boot) and advance the search here, without
      // a reboot. Only a failure costs one.
      removeFile("/unstableboot");
      powerCalLo = powerCalCand;
      beginPowerCalibrationProbe();
    }
  } else if (!bootStableMarked && millis() > STABLE_UPTIME_MS) {
    bootStableMarked = true;
    removeFile("/unstableboot");
  }

  float frame_rate = 30;
  if (idlePattern == PATTERN_DEFAULT || idlePattern == PATTERN_FIREFLIES)
    frame_rate = idleFrameRate;
  int delay_time = (int)(1000.0f / frame_rate - (millis() - loop_start));

  xSemaphoreGiveRecursive(render_mutex);

  // Poll the button here (instead of in networkTask) so it's responsive
  // immediately at boot — networkTask spends several seconds connecting to
  // WiFi before reaching its polling loop. DIM/CYCLE actions run inline here;
  // ACCESS_POINT defers to networkTask via apTriggerRequested because the
  // captive portal blocks until WiFi connects, which would freeze rendering
  // (including the AP rings) if it ran on the loop task.
  checkFadePin();

  delay(max(delay_time, 1));  // always yield at least 1ms so idle task feeds WDT
}

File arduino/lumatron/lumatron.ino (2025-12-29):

#include <Adafruit_NeoPixel.h> 

#define FRAME_MILLIS 24
#define PIN D10

#define SIZE 120 
#define RAW_SIZE 240
#define MAX_NEIGHBORS 4
int dupes_to_uniques[] = {0x00590000,0x00580001,0x00570002,0x00560003,0x00550004,0x00540005,0x00530006,0x00520007,0x00510008,0x00500009,0x004f000a,0x004e000b,0x004d000c,0x004c000d,0x004b000e,0x004a000f,0x00490010,0x00480011,0x00470012,0x00460013,0x00450014,0x00440015,0x00430016,0x00420017,0x00410018,0x00400019,0x003f001a,0x003e001b,0x003d001c,0x003c001d,0x00ef001e,0x00ee001f,0x00ed0020,0x00ec0021,0x00eb0022,0x00720023,0x00710024,0x00700025,0x006f0026,0x006e0027,0x006d0028,0x006c0029,0x006b002a,0x006a002b,0x0069002c,0x0068002d,0x0067002e,0x0066002f,0x00650030,0x00640031,0x00630032,0x00620033,0x00610034,0x00600035,0x005f0036,0x005e0037,0x005d0038,0x005c0039,0x005b003a,0x005a003b,0x00ea0073,0x00e90074,0x00e80075,0x00e70076,0x00e60077,0x00e50078,0x00e40079,0x00e3007a,0x00e2007b,0x00e1007c,0x00a4007d,0x00a3007e,0x00a2007f,0x00a10080,0x00a00081,0x009f0082,0x009e0083,0x009d0084,0x009c0085,0x009b0086,0x009a0087,0x00990088,0x00980089,0x0097008a,0x0096008b,0x0095008c,0x0094008d,0x0093008e,0x0092008f,0x00910090,0x00e000a5,0x00df00a6,0x00de00a7,0x00dd00a8,0x00dc00a9,0x00db00aa,0x00da00ab,0x00d900ac,0x00d800ad,0x00d700ae,0x00d600af,0x00d500b0,0x00d400b1,0x00d300b2,0x00d200b3,0x00d100b4,0x00d000b5,0x00cf00b6,0x00ce00b7,0x00cd00b8,0x00cc00b9,0x00cb00ba,0x00ca00bb,0x00c900bc,0x00c800bd,0x00c700be,0x00c600bf,0x00c500c0,0x00c400c1,0x00c300c2};
long long neighbors[] = {0x001d003b0001001e,0xffffffff00020000,0xffffffff00030001,0xffffffff00040002,0x0041004000050003,0x0041004000060004,0xffffffff00070005,0xffffffff00080006,0xffffffff00090007,0x005f005e000a0008,0x005f005e000b0009,0xffffffff000c000a,0xffffffff000d000b,0xffffffff000e000c,0x002d002c000f000d,0x002d002c0010000e,0xffffffff0011000f,0xffffffff00120010,0xffffffff00130011,0x0050004f00140012,0x0050004f00150013,0xffffffff00160014,0xffffffff00170015,0xffffffff00180016,0x006e006d00190017,0x006e006d001a0018,0xffffffff001b0019,0xffffffff001c001a,0xffffffff001d001b,0x0000003b001e001c,0x003b001f001d0000,0xffffffff0020001e,0xffffffff0021001f,0xffffffff00220020,0x0059003c00230021,0x0059003c00240022,0xffffffff00250023,0xffffffff00260024,0xffffffff00270025,0x0064006300280026,0x0064006300290027,0xffffffff002a0028,0xffffffff002b0029,0xffffffff002c002a,0x000f000e002d002b,0x000f000e002e002c,0xffffffff002f002d,0xffffffff0030002e,0xffffffff0031002f,0x004b004a00320030,0x004b004a00330031,0xffffffff00340032,0xffffffff00350033,0xffffffff00360034,0x0073007200370035,0x0073007200380036,0xffffffff00390037,0xffffffff003a0038,0xffffffff003b0039,0x001e0000001d003a,0x00590022003d0023,0xffffffff003e003c,0xffffffff003f003d,0xffffffff0040003e,0x000500040041003f,0x0005000400420040,0xffffffff00430041,0xffffffff00440042,0xffffffff00450043,0x0077005a00460044,0x0077005a00470045,0xffffffff00480046,0xffffffff00490047,0xffffffff004a0048,0x00320031004b0049,0x00320031004c004a,0xffffffff004d004b,0xffffffff004e004c,0xffffffff004f004d,0x001400130050004e,0x001400130051004f,0xffffffff00520050,0xffffffff00530051,0xffffffff00540052,0x0069006800550053,0x0069006800560054,0xffffffff00570055,0xffffffff00580056,0xffffffff00590057,0x003c002300220058,0x00770045005b0046,0xffffffff005c005a,0xffffffff005d005b,0xffffffff005e005c,0x000a0009005f005d,0x000a00090060005e,0xffffffff0061005f,0xffffffff00620060,0xffffffff00630061,0x0028002700640062,0x0028002700650063,0xffffffff00660064,0xffffffff00670065,0xffffffff00680066,0x0055005400690067,0x00550054006a0068,0xffffffff006b0069,0xffffffff006c006a,0xffffffff006d006b,0x00190018006e006c,0x00190018006f006d,0xffffffff0070006e,0xffffffff0071006f,0xffffffff00720070,0x0037003600730071,0x0037003600740072,0xffffffff00750073,0xffffffff00760074,0xffffffff00770075,0x005a004600450076};

#define MAX_HEADS 64
int head_count = 1;
int fluid_heads[MAX_HEADS];
int fluid_head_buffer[MAX_HEADS];
double fluid_values[RAW_SIZE];
double render_values[RAW_SIZE];

int start_r = 0x25;
int start_g = 0xff;
int start_b = 0x59;
int end_r = 0x00;
int end_g = 0x60;
int end_b = 0x7c;

Adafruit_NeoPixel strip = Adafruit_NeoPixel(RAW_SIZE, PIN, NEO_GRB + NEO_KHZ800);

void setup() {
  Serial.begin(115200);
  strip.begin();
  randomSeed(13);
}

void loop() {
  int loop_start_time = millis();
  double target_head_count = SIZE / 30.0;
  double head_ratio = head_count / target_head_count;
  double dampening_factor = 1 + head_ratio*head_ratio*5;

  int new_head_count = 0;

  for (int i = 0; i < head_count; i++) {
    int head = fluid_heads[i];
    for (int j = 0; j < MAX_NEIGHBORS; j++) {
      if (new_head_count >= MAX_HEADS) {
        break;
      }
      int n = (neighbors[head] >> (j * 16)) & 0xffff;
      if (n == 0xffff) {
        continue;
      }
      double x = fluid_values[dupes_to_uniques[n] & 0xffff] + 0.01;
      x *= dampening_factor / 1.5;
      if (x * 0x10000 < random(0xffff)) {
        fluid_head_buffer[new_head_count++] = n;
      }
    }
  }

  double spontaneous_combustion_chance = 0.01 / (head_ratio * head_ratio);
  if (new_head_count < MAX_HEADS && spontaneous_combustion_chance * 0x10000 > random(0xffff)) {
    fluid_head_buffer[new_head_count++] = random(SIZE);
  }

  for (int i = 0; i < RAW_SIZE; i++) {
    strip.setPixelColor(i,0);
  }
  for (int i = 0; i < new_head_count; i++) {
    int uniques = dupes_to_uniques[fluid_head_buffer[i]];
    strip.setPixelColor(uniques & 0xffff, 0x303030);
    strip.setPixelColor(uniques >> 16 & 0xffff, 0x303030);
  }

  if (new_head_count != 0) {
    memcpy(fluid_heads, fluid_head_buffer, sizeof(fluid_heads));
    head_count = new_head_count;
  }
  for (int i = 0; i < head_count; i++) {
    int uniques = dupes_to_uniques[fluid_heads[i]];
    fluid_values[uniques & 0xffff] = 1.0;
    fluid_values[uniques >> 16 & 0xffff] = 1.0;
  }

  double alpha = 0.3;
  for (int i = 0; i < RAW_SIZE; i++) {
    fluid_values[i] *= 0.86;

    double v = fluid_values[i] * fluid_values[i];
    double v2 = render_values[i] * (1-alpha) + v * alpha;
    render_values[i] = v2;

    int r = (start_r * v + end_r * (1 - v)) * v2;
    int g = (start_g * v + end_g * (1 - v)) * v2;
    int b = (start_b * v + end_b * (1 - v)) * v2;
    strip.setPixelColor(i, b + (g<<8) + (r<<16));
  }
  strip.show();
    
  int delay_time = FRAME_MILLIS - (millis() - loop_start_time);
  if (delay_time > 0) {
    delay(10);
  }
}

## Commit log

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2022-03-20 Small improvements to website. Plus a bug fix
    [bomberman.py, engine.py, pacman.py]
2022-04-19 Fixed IP update request to actually work
    [server.js]
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2022-05-07 Updated victory rendering and adjusted games to play music at correct timing
    [audio.py, bomberman.py, colorwar.py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]
2022-05-10 Fixed up timing and flow of victory animation
    [engine.py]
2022-05-20 Added tower.obj just in case someone wants it.
    [tower.obj]
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2022-05-21 Fixed broadcast_state not being called during idle animation
    [engine.py]
2022-05-23 Refactored engine + games to use new Game class with inheritence. Likely bugs introduced.
    [bomberman.py, colorwar.py, engine.py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]
2022-05-24 Mario party style. And fixed settings bug.
    [bomberman.py, engine.py, main.py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]
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2022-05-28 Some fixes to music handling
    [audio.py, engine.py]
2022-05-28 dodged null victor bug
    [engine.py]
2022-05-28 Fixes for playing waiting song properly
    [engine.py, pacman.py, server.js]
2022-05-28 Fixed pacman player colors
    [main.py, pacman.py]
2022-05-28 Some more fixes to audio handling
    [audio.py]
2022-05-29 Fixed idle state with dummy idle game.
    [engine.py, main.py]
2022-05-29 Fixed follow y-rotation bug
    [engine.py]
2022-05-29 Fixed game not resetting properly on game restart
    [engine.py]
2022-05-29 Fixed pacman victor. And cleaned up raw pixels in engine.py
    [engine.py]
2022-05-29 added volume slider and fixed some audio problems
    [engine.py]
2022-06-22 Some fixes to orbclient code
    [orbclientaudio.py]
2022-06-23 Added skip button
2022-06-28 Fixed problem with stdout messages having extra whitespace
    [audio.py, engine.py, server.js]
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2022-07-20 Some fixes to WebRTC
    [server.js]
2022-07-20 Catch some socket errors and some logging tweaks
    [server.js]
2022-07-20 Fixes for dropping old responses on client side and not sending duplicate game state data to clients
    [engine.py, server.js]
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2022-07-20 Some fixes to multi-socket handling and IP address parsing
    [server.js]
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2022-07-20 Added higher precision to playload timestamps to prevent ignoring messages sent within 1 millisecond
    [main.py, server.js]
2022-07-20 Fixed calculation of precise time
    [server.js]
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2022-07-21 Fixed orb version of engine import
    [engine.py]
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2022-08-03 Fixed issues with bomberman and basedefense
    [bomberman.py, engine.py, pacman.py]
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2022-08-14 Added 3D printing stuff to source control. Tweaked violet
    [paper holder holder.scad, simple cuff.scad, vertex.scad]
2022-08-17 Restored joystick and fixed pacman
    [pacman.py]
2022-08-25 Fixed pacman and other minor changes to games.
    [pacman.py]
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2022-08-31 Some fixes to handle case where python is not ready yet
    [engine.py, server.js]
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2022-09-13 Resolved conflict
    [vertex.scad]
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2022-11-09 Fixed typo and added logging of used and skipped messages over the different sockets
    [server.js]
2022-11-19 -g is now a permanent game setting, fixed push in dominion
    [server.js]
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2023-06-17 Fixed snektron bug and use time input type in home page.
    [snektron.py]
2023-06-17 Improved time picker appearance and prevent path finding in pixels from stalling out.
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2023-06-29 Refactored neopixel write slightly. Some smalled fixes for helmetron.
    [engine.py, orbpixel.py]
2023-07-04 A couple bug fixes in pixels.
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2023-07-31 fix for out of order call
    [server.js]
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2023-08-26 Config tweaks. Fixed problem with endtimes after midnight.
    [engine.py]
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2023-09-18 Don't treat response as logs if we didn't request them
    [server.js]
2023-09-18 Fixed old references to self
    [server.js]
2023-09-18 Fixed pm2 restart and added logs
    [server.js]
2023-09-18 reversed update check logic
    [server.js]
2023-09-20 Fix issue with pm2 cleanup
    [server.js]
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2023-09-20 Some fixes to ping and pm2 cleanup
    [server.js]
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2023-09-22 increased connection check timeout and added connection check error logging
    [server.js]
2023-10-03 Fixed issue with wall generation using black pixels.
    [engine.py]
2023-10-17 Fixed git pull checking code
    [server.js]
2023-10-24 Reset laser data on reset and refactor button creation.
2023-10-24 Correctly handle idle fades that span midnight.
    [engine.py]
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2023-10-25 Catch error with JSON parsing of POST.
    [server.js]
2023-10-25 Fixed reference to undefined payload
    [server.js]
2023-10-25 Attempt to fix bad content type error
    [server.js]
2023-10-25 Attempt to fix bad content type error again
    [server.js]
2023-10-25 Fix for post handling
    [relay.js, server.js]
2023-10-26 Final fix for idle timer. Plus removed stand cylindar from emulator.
    [engine.py]
2023-10-27 More prefs in controller and some fixes.
    [engine.py]
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2023-11-02 More correct optimization, but still buggy
    [engine.py]
2023-11-02 Fixed small bug in render_ring
    [engine.py]
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2023-11-06 Fixed typos in games config.
    [orbpixel.py]
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2023-11-06 More correct toggle switch code.
    [engine.py]
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2023-11-07 Fixed bug with display before start time introduced from refactor.
    [engine.py]
2023-11-08 Off state display_pixels now set correctly.
    [engine.py]
2023-11-10 Fixed color set to hex value
    [engine.py]
2023-11-13 Fixed color prefs and better handling of default prefs.
    [engine.py]
2023-11-15 Moved violet to last color. Minor engine bug fix.
    [engine.py]
2023-11-20 Nav bar is cut off in Chrome mobile. Seeing if this'll fix things
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2023-11-21 Fix for idle frame rate.
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2023-11-27 Setup but didn't test basic text printing.
    [engine.py, orb.js]
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2023-11-28 fixes to rp2040 code
    [code.py, orbpixel.py]
2023-11-28 Some uart fixes and base install serial fix
    [code.py, orbpixel.py]
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2023-11-28 some uart fixes
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2023-11-29 some fixes for serial over usb
    [orbpixel.py]
2023-11-29 Added handling of board connection failing and updated SCORPIO code
    [code.py, orbpixel.py]
2023-11-29 removed reset output buffer line
    [orbpixel.py]
2023-11-29 Fixed external board reference
    [orbpixel.py]
2023-11-30 fixed error with processing config on scorpio
    [code.py]
2023-11-30 Added static pixel buffer to mitigate garbage collection, added script that mounts and updates external board code, added reset signal to pi code on initial run
    [code.py, orbpixel.py]
2023-11-30 Fixed external board update code
2023-11-30 Added missing global reference
    [orbpixel.py]
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2023-11-30 Attempt to fix pixel byte order.
    [engine.py, orbpixel.py]
2023-11-30 Attempt 2 to fix pixel byte order.
    [orbpixel.py]
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2023-12-01 Moved sleep timers around a bit to try and prevent hard fault on usb access
    [code.py]
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2023-12-02 moved usb settings into reset function for feather
    [code.py]
2023-12-02 Removed skip reset logging
    [orbpixel.py]
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2023-12-03 Attempt to fix timing issues
    [code.py, orbpixel.py]
2023-12-03 Fixed not reading proper amount of sync bytes
    [code.py]
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2023-12-03 Added watchdog timer to prevent long stalls
    [code.py]
2023-12-03 Fixed byte order for external board.
    [orbpixel.py]
2023-12-03 Fixed byte order for external board attempt 2.
    [orbpixel.py]
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2023-12-06 Fixed issue with pulses idle pattern and neopixel display.
    [engine.py]
2023-12-07 Replace 5 with S
    [engine.py]
2023-12-07 Replace 5 with S in short strings.
    [engine.py]
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2023-12-16 Change to hopeful fix saving bug.
    [engine.py]
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2023-12-21 Changed handling of board restarting to prevent loop
    [orbpixel.py]
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2023-12-31 Fix bomberman explosion bug.
    [bomberman.py]
2023-12-31 Added logging of glitches per minute to feather
    [code.py]
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2023-12-31 Fixed index out of range error in orb pixel
    [orbpixel.py]
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2024-01-06 Code to prevent lamp from flashing and some box stuff.
    [engine.py]
2024-01-06 Bug fix for lamp code
    [engine.py]
2024-01-16 IDLE config now adds to idles patterns rather than prevent any others from being used. Plus new mandala topology
    [engine.py]
2024-01-20 Fixed pixel data error
    [orbpixel.py]
2024-01-20 Fixed feather meta bug
    [code.py]
2024-01-20 Fixed using wrong value for hash
    [code.py, orbpixel.py]
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2024-01-21 Feather will log and skip frames that are invalid
    [code.py]
2024-01-22 Small error check when placing ghosts.
    [pacman.py]
2024-01-22 Correction for '.' in text.
    [engine.py]
2024-01-23 Fixed logging of feather glitches and tweaked data header
    [code.py, orbpixel.py]
2024-01-24 Some adjustments to failure logging
    [code.py]
2024-01-24 Fix divide by zero
    [code.py]
2024-01-24 Restart feather after 15 glitches in a minute
    [code.py]
2024-01-24 Add no serial connection as a failure in feather
    [code.py]
2024-01-24 Actual fix for json that spans multiple stdout messages.
    [orb.js]
2024-01-25 Some modifications to feather code to try and handle underlying USB problems
    [code.py, orbpixel.py]
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2024-01-29 deleted unused files and fixed config and bas install
    [lib.js, orbclientaudio.py]
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2024-01-30 Cleaned up some calls to execute and added ability to reboot pi if pm2 is not running
    [gitupdate.js, server.js]
2024-01-30 Fixed check for pm2 in git restart
    [gitupdate.js]
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2024-02-01 fix pulse clamping
2024-02-19 change write timeout to feather and don't restart pi connection on failure
    [orbpixel.py]
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2024-03-02 Increased sleep when board resets to capture log that it is resetting
    [code.py]
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2024-04-01 Hopefully fixed saves overlapping 'Restore Default' button.
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2024-05-21 Leave games button, and fixed background in saved prefs list.
    [engine.py, main.py]
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2024-06-16 Some reorganization. Ability to set alias with a button click. Better box top.
    [boxtop.scad]
2024-06-18 Fix for weather when there's no internet and no preexisting data.
    [engine.py]
2024-06-26 Fixed a couple bugs.
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2024-07-16 Blackhole project plus some minor fixes.
    [engine.py]
2024-07-17 Several small bug fixes.
    [engine.py]
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2024-07-22 Angled walls and used correct version of standoff.scad.
    [angledstandoff.scad, standoff.scad]
2024-08-17 A couple new patterns plus fixed ingesting of pngs and some other small refactors.
2024-08-28 Fixed bug with saving new prefs.
    [prefs.py]
2024-08-29 Some cleanup and fixing of small bugs.
    [prefs.py]
2024-08-29 Restored delegate pattern in prefs of set_idle and fixed a related bug.
    [main.py, prefs.py]
2024-08-29 Fixed weird import bug.
    [main.py]
2024-09-01 Fixed ripples to work with no longer calling update_prefs
    [engine.py]
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2024-09-10 Fixed several math errors. Made it so walls can snap in place for 3D printed covers.
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2024-10-06 Box redesign (including supporting two sided boxes.
    [boxtop3D.scad]
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2024-10-23 Fixed border svg for folds. New helmetron.
    [angledstandoff.scad]
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2024-11-10 Fix to game import weirdness.
    [bomberman.py, colorwar.py, main.py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]
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2024-11-13 Ability to print fold wall halves seperately. Plus various math fixes and cleanup.
2024-11-14 Restored led supports for fold walls, plus more math corrections.
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2025-01-16 Various minor fixes. Plus some creation cruft.
    [prefs.py]
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2025-02-25 A few new designs, plus some more creation bug fixes.
    [snapmount.scad]
2025-02-26 Proper led support offsets for non-integer edge length. Reset PART_ID start/end on change project in creation console.
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2025-03-21 Fixed dimmer bug, and issue with simplified models.
    [prefs.py]
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2025-03-26 Further work on butterfly piece (with a relevant bug fix) and other very minor changes.
    [prefs.py]
2025-04-04 Fixed small slots for walls.
2025-04-08 Small box with remote. Plus fix post process print indecies to conform to new order.
2025-04-15 Redid Mieke's rectangle, and related fixes.
    [boxsnapmount.scad]
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2025-04-19 Password visibility toggle when adding wifi. Correction to end cap offset sign for LED supports.
2025-04-26 Another LED support fix. Fixed rendering issue for some covers.
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2025-05-06 Better partID placement. Fixed infinite loop with circular topologies. Made support hook for icicle piece.
    [snapmount hook.scad]
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2025-05-12 Moved dimmer to timer_prefs. Fixed timer off message.
    [engine.py, prefs.py]
2025-05-13 Fix for infinite loop with new dimmer refactor.
    [prefs.py]
2025-05-14 Tweek truncoct params. Get new usbc port hole for endcap to work.
    [powercore2.scad, usbc sleeve (luma).scad]
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2025-05-17 Some adjustments to relay pads and added pads to USB castellated edges
    [pi interface.kicad_pcb]
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2025-05-21 changed wifi check frequency and fixed wlan0 use to check for it first
    [orb.js]
2025-05-21 Fixed problem with scope
    [gitupdate.js]
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2025-06-04 Hack fix for usb-c connectors, plus tweaks to minibox.
    [solderjig.scad, usbc hack mount.scad]
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2025-06-18 Made side to side leeway of snapmounts larger.
    [snapmount.scad]
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2025-06-24 Fix bug that constantly send tether updates.
    [orb.js]
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2025-06-29 Logging config. Plus fix infinite loop when turning timer off when in OFF state.
    [orb.js, prefs.py]
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2025-06-30 Revert "Better handling of turning timer off."
    This reverts commit 7253d2ff2a1ce98b69faaf20629bceacdb8b873c.
    [prefs.py]
2025-06-30 Corrected previous rolled back commit. Fixed borromean topology. A couple minor style changes.
    [main.py, prefs.py]
2025-07-02 Various logging changes to help figure out some thorny problems.
    [orb.js, relay.js, server.js]
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2025-07-09 USB solder jig and other tweeks to creation scad files. Plus a log for restarting.
    [boxsnapmount.scad, solderjig_pi+pcb.scad, solderjig_wifiusb.scad]
2025-07-09 Extra error check for admin commands.
    [relay.js]
2025-07-09 Likely fix to server restarting at midnight
    [orb.js]
2025-07-09 Some better error handling for a couple admin commands.
    [orb.js]
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2025-07-14 Improved error flow for tethered orbs.
    [orb.js]
2025-07-14 Error handling for regitration. Some scaffolding for passing info from orbs/server to registration page. Trying changing uuids for diff orbs.
    [relay.js]
2025-07-14 Closed extra socket in case that fixes a connection bug.
    [orb.js]
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2025-07-14 Fixed color picker appearance and staying up to date.
    [relay.js]
2025-07-15 Passing around orb info. Plus converted many console.error to console.log.
    [engine.py, lib.js, orb.js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]
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2025-07-16 Send correct orb info back.
    [orb.js, relay.js]
2025-07-16 Some wobble to stl rotation. Scroll in registration view.
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2025-07-17 Added more stls and corrected cuboct.
    [cuboct.stl, greatrhomb.stl, helmet (5 pixels per edge).stl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]
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2025-07-20 Zero state orb instrallation instructions for registration page. Plus other small registration fixes.
    [engine.py]
2025-07-22 Have missing orb page redirect to homepage.
    [relay.js]
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2025-07-22 Admin fix. Removed some logging. Fix for first pixel rendering.
    [engine.py, relay.js]
2025-07-24 Fixed copper to edge padding on pcb
    [pi interface.kicad_pcb]
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2025-07-25 Correct blue. Avoid lumatron.setup.
    [engine.py]
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2025-08-16 Fix sharp angle fold walls printed separately sticking out the bottom
2025-08-19 Fixed removing LED supports for flipped walls printed together with a negative y rotation angle.
2025-08-21 Likely fixed wrong command return race condition bug.
    [orb.js]
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2025-08-28 Correct stl demo orientation and better default pattern. Star designs.
    [star1.stl, star1_full.stl, star2.stl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]
2025-08-29 Corrented radial waves direction and added toggle to reverse.
    [prefs.py]
2025-08-29 New star iteration and fixed some related minor bugs.
    [star1.stl, star1_full.stl, star2.stl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]
2025-10-07 Better necklace stl. Reset registration button.
    [butterfly.stl, butterfly_full.stl, necklace.stl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]
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2025-10-22 Little bit of logging to understand prefs not loading. Updates to neo-orbitron bits.
    [bottom.scad, roundedcube.scad, strut corner.scad]
2025-10-27 Config to invert axese for playing games.
    [engine.py]
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2025-10-29 Removed no longer used conversion code from prefs.py
    [prefs.py]
2025-10-29 Another logging tweak to help find pref.json dropping bug.
    [prefs.py]
2025-10-31 Fix for bomberman crash.
    [bomberman.py]
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2025-11-15 Fixes in power calibration.
    [engine.py]
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2025-11-19 Better tether error checking.
    [orb.js]
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2025-11-19 Trying to avoid blip when toggling useTimer back and forth.
    [prefs.py]
2025-11-24 Reinforcer for vertical pipe connection.
    [angledstandoff.scad, boxsnapmount.scad, lumatron card.scad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]
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2025-11-29 More logging for restart on code update bug.
    [prefs.py]
2025-11-29 Another bug fix attempt, plus some cleanup.
    [main.js, prefs.py]
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2025-12-05 Corrected dedeccycle orientation.
    [dodeccycle.stl, dodeccycle_full.stl]
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2025-12-06 Don't save empty prefs + pipe jammer.
    [pipe.scad]
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2025-12-09 Remote input correction 2.
    [engine.py]
2025-12-09 Remote input correction 3.
    [engine.py]
2025-12-09 Remote input correction 4.
    [engine.py]
2025-12-09 Remote input correction 5.
    [engine.py]
2025-12-09 Remote input correction 6.
    [engine.py]
2025-12-09 Remote input correction 7.
    [engine.py]
2025-12-09 Weird power button rendering issue obviated by making border solid color (that changes with dimmer level)
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2025-12-16 Tetra pure and correction to basis creation.
    [tetratrue.stl, tetratrue_full.stl]
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2025-12-23 Important saving bug fix. Plus starting work on tricolor color option.
    [prefs.py]
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2026-01-31 Tested on pi and corrected.
    [engine.py]
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2026-02-05 Shorted spurious trigger time.
    [engine.py]
2026-02-09 Diagnostic from tricker prefs bug.
    [prefs.py]
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2026-02-10 Trying no longer caching saved pref.
    [prefs.py]
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2026-02-11 Avoid initial start trigger
    [engine.py]
2026-02-11 Pin calibration and pref hot fix.
    [engine.py, prefs.py]
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2026-02-26 Avoid LED supports across from usb-c ports
2026-02-26 Lining up emulator correctly.
    [diamond.stl, diamond_full.stl, mobius.stl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]
2026-02-27 A couple small fixes.
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2026-03-17 Dry run of frest server install. Hot fix 4.
    [server.js]
2026-03-17 Dry run of frest server install. Hot fix 6.
    [server.js]
2026-03-19 Fixed admin alt server issues.
    [relay.js]
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2026-03-25 More snake exploration and related fixes.
    [snake3.stl, snake3_full.stl, snake4.stl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]
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2026-03-26 Some likely fixes for libraries.
    [orbpixel.py]
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2026-04-08 Working on wifi enabled arduino. Need to make a change to admin.
    [partitions.csv, rhombtrue_full.stl]
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2026-04-09 Arduino: backup system, timing prefs, security, and relay fixes.
    - Precomputed nextBackupMs for 2am auto-backup (same pattern as nextEventMs)
    - Added backup/restore system with LittleFS savedprefs directory
    - One-off migration for camelCase → ALL_CAPS config keys
    - Fixed JsonPairConst error in handleRestoreFromBackup
    - Skip geometry fetch when PIXELS is empty or "null"
    - Move WebSocket init before geometry load so admin commands always work
    - Added WS connected/disconnected serial logging
    - Fix relay orbUpkeep disconnecting silent Arduino orbs by resetting
    lastActivityTime on ping (Pi stays alive via pixel data stream; Arduino doesn't)
    [esp32.ino, relay.js]
2026-04-09 Revert "Arduino: backup system, timing prefs, security, and relay fixes."
    This reverts commit debf49b19d361bd49a6c327a36fc5ee72d1ede06.
    [esp32.ino, relay.js]
2026-04-09 Reapply "Arduino: backup system, timing prefs, security, and relay fixes."
    This reverts commit 0cbe4f66541bb5a208b4f94829bfcf041e3859d2.
    [esp32.ino, relay.js]
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2026-04-10 Admin console improvements: don't display 404, commit/version status that works for arduino as well
    [lamp base insert.scad]
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2026-04-10 Correctly update server commit. Minor arduino bug fixes.
    [esp32.ino, relay.js]
2026-04-11 Hopefully, fix server-side arduino compilation errors.
    [esp32.ino]
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2026-04-11 Fix to admin version display.
    [relay.js]
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2026-04-12 Fixed Set ORB_KEY for arduino.
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2026-04-17 Printing setup for new desklamp and associated fixes and generalizations.
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2026-04-21 Return 200 for wrong branch.
    [relay.js]
2026-04-21 Caught and fixed bug in snake topology and related reason it passed under the radar.
    [snake.stl, snake_full.stl]
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2026-04-23 Actual fix for pcb-offset in middle of foldwalls.
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2026-04-23 Removed zip of logs request. Plus some minor fixes.
    [orb.js, relay.js]
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2026-04-25 Feedback that login code was wrong.
    [orb.js]
2026-04-26 Fixed greatrhomb's stl
    [greatrhomb.stl]
2026-04-27 Prevent power button in home page from opening orb.
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2026-04-28 Fixed firmwareVersions endpoint calls.
    [relay.js]
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2026-04-30 New pcb for arduino box. Plus actually saved scad files and organized them a bit.
    [lamp base insert.scad, pi interface.kicad_pcb, powercore.scad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]
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2026-05-04 Send correct CI message to Pis.
    [relay.js]
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2026-05-04 Dimmer instant button feedback. Plus corrected arduino behavior.
    [engine.py, esp32.ino]
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2026-05-07 Admin changes: removed alias editing; added ability to viewed error log.
    [orb.js]
2026-05-07 Handle fact that pkill throws error when no python processes exist.
    [orb.js]
2026-05-07 Added icosidodectrue git files, plus some bugs fixes found in the process.
    [icosidodectrue.stl, icosidodectrue_full.stl]
2026-05-09 Got s3 chip to work and optimized memory to work with 1200 pixels. Default arduinos to turn dimmer to 1 on power up.
    [icosidodectrue_full.stl, swivelmount.scad]
2026-05-09 Likely fix to Update firmware button in admin console.
    [esp32.ino, relay.js]
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2026-05-09 Additional fix for the update firmware button.
    [esp32.ino, relay.js]
2026-05-09 Fixes to arduino patterns, plus sanity check on admin configs to save.
    [esp32.ino, patterns.h]
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2026-05-11 Avoid network blocking render start
    [esp32.ino]
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2026-05-11 Fixed scope of priorityToCurrentText.
    [orb.js]
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2026-05-16 Updated arduino pcb. Ota updates now block rendering with extra indicator pixel.
    [seeeduino interface.kicad_pcb]
2026-05-19 Rendering differently to avoid wifi induced glitches.
    [esp32.ino, patterns.h]
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2026-06-02 SKIP_AC_ON_POWER defaults to true when remote pin is set
    [esp32.ino]
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2026-06-02 Avoid redundant currentprefsname.txt writes.
    [esp32.ino]
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2026-06-03 Flash writes use mutex to avoid interferring with rendering.
    [esp32.ino, patterns.h]
2026-06-04 Fixed issues with timer getting started on arduino.
    [esp32.ino]
2026-06-05 Fixed various issues with fading and schedule events.
    [esp32.ino]
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2026-06-06 Avoid writing to prefs or timingprefs if it is the same.
    [esp32.ino]
2026-06-06 Avoid fading out/in when schedule presets are the same
    [esp32.ino, prefs.py]
2026-06-11 Fixed power calibration for arduino.
2026-06-12 Trying to deal with arduino brownout
    [esp32.ino]
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2026-06-12 Surface reset reason for arduino in admin.
    [esp32.ino, relay.js]
2026-06-13 Arduino to use epoch time for timestamp to be consistent across reboots.
    [esp32.ino]
2026-06-13 Broadcast update to connected controllers on relay reconnect/reboot.
    [relay.js]
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2026-06-27 Fixed one-off emulator interferring with other emulation.
    [emulation.js, orb.js, relay.js]
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2026-07-14 Fix for occational flash during scheduling fade in/out.
    [esp32.ino]
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2026-08-05 Some API documentation updates, and bits needed to fix Raph's piece.
    [restapi.js]
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2026-08-11 Flasher website for resetting an arduino remotely.
    [relay.js]
2026-09-15 Fixed viewing logs older than the most current.
    [orb.js]
2026-09-15 Support for color types in arduino. Collapse color variables. Backup mention ip address for access point.
    [middle.scad]
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2026-09-17 3D printed Ravenstear and relate vertex seam code. Updated micro box to avoid small negative space debossing bit that don't print well.
    [ravenstear.stl, ravenstear_full.stl]
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2026-09-19 Fix for split deadend wall LED support placement. Various files and changes for dodeccycle lamp.
    [dodeccycle2.stl, dodeccycle2_full.stl, lamp base insert.scad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]
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2026-10-10 Fixed periodic sparkle alignment in arduinos, plus another sparkle bug.
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2026-11-04 Fix for stale outgoing sockets from orbs.
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2026-11-06 Avoid sharpest angle when interizing equal length edges, and another fix to avoid covers that can't print for starframe.
